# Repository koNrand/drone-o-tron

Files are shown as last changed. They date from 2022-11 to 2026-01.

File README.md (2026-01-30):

# *Drone o Tron* ->[Veröffentlichung/Publication](https://www.instagram.com/p/Cwxmp4OM5u2/?img_index=1)<-

Für Neulinge: Lade dieses Repository herunter, um die Dateien zu benutzen. Ein Öffnen über den Browser funktioniert in der Regel nicht! Klicke dazu auf den grünen Button 'Code' und dann auf 'Download ZIP'.

For newbies: Download this repository to use the files. Opening them via the browser usually does not work! Click on the green button 'Code' and then on 'Download ZIP'.

----------

english below

## DE:

Der ***Drone o Tron*** (DoT) ist einstimmiger Minisynthesizer mit Ribbonklaviatur, welche über ein Monoaudiokabel gesteuert wird. Inspiration hierfür sind der [Monotron]((https://www.korg.com/de/products/dj/monotron/index.php)) von Korg oder die [Pocket Operator](https://teenage.engineering/products/po) von Teenage Engineering. Der Synthesizer soll auf eine einzige, handliche Platine passen und mit zwei AAA-Batterien betrieben werden. Außerdem soll es einige einstellbare Effekte und Filter geben, über welche der Sound verändert werden kann.

In den Pre-Versionen bestehen aus der Simulation in [LTSpice](https://www.analog.com/en/design-center/design-tools-and-calculators/ltspice-simulator.html) und dem Testaufbau auf dem Steckbrett. Wer Interesse am kompletten Prozess des Projektes hat, oder Erklärungen zu den Teilschaltungen sucht, kann im `.archive`-Ordner vorbeischauen. Ich habe dort in den `README.md` die entsprechenden Infos und auch Erklärvideos zu den groben Grundlagen verlinkt. 

Als finalen Schritt im Projektmanagement und erste Hauptversion nach Simulation und Steckbrettaufbau habe ich nun  den Drone o Tron in [KiCad](kicad.org/) Schaltplaneditor und anschließend im Boardeditor aufgebaut. Ich habe auch hier nochmal einige Änderungen vorgenommen, neue Funktionen hinzugefügt und diese in einem selbst illustrierten Platinenlayout zusammenkommen lassen.

Eine Auflistung aller Änderungen findet sich in der `CHANGELOG.md`.

Die voll funktionsfähige Platine lässt sich für den eigenen Gebrauch mithilfe der `gerberfiles_v_1_0_rev1`-Ordner bestellen. EInfach die geünschte Version und dann bei PCB-Produzenten wie JLCPCB bestellen. Eine interaktive Aufbauhilfe (`interactive_assembly_list.html`) in Form einer .html Datei ist auch vorhanden, sodass die benötigen Bauteile auch keine Hürde darstellen.
Mögliche Händler hier sind LCSC, (zugehörig zu JLCPCB, einfachste Lösung) Mouser, Reichelt, TME, uvm.

### Außer dem KiCadprojekt sind enthalten:
- einige gerenderte Aufnahmen aus der 3D-Ansicht von KiCad, welche alle 3D-Bauteilmodelle, die Illustrationen und meien favorisierte Farbe für den Lötstoplack (lila) enthalten.
- S/W Vektorgrafikaufnahmen des Boards, welceh mithilfe des Board2Pdf-Plugins erstellt wurden
- eine BOM-Tabelle (Bill of Material) aller benötigter Bauteile
- eine aussführliche Bescheibung der Berechnungen, die ich für den Spannungsteiler der Klaviatur vorgenommen habe, sodass der NE555 als wohltemperierter VCO für tonale Musik verwendet werden kann

## Disclaimer
Mit jegllicher Änderung am Schaltplan oder dem Boarddesign erlischt 
die Nutzungserlaubnis der Board-Artworks, meines Logos sowie der Verwendung meiner
Referenzen. Eine Nennung des Originalurhebers ist jedoch unbedingt erwünscht
und entsprechend zu kennzeichnen. Eine Veröffentlichung der veränderten Schaltung muss unter derselben Creative Commons Lizens CC BY-NC-SA erfolgen. Die 
kommerzielle Nutzung ist ausgeschlossen. Alles frei nach dem Motto: Fair use only! ;-)

Mehr Informationen unter: https://creativecommons.org

Open hardware FTW <3

-------

## EN:
The ***Drone o Tron*** (DoT) is monophonic mini synthesizer with ribbon keyboard, which is controlled by a mono audio cable. Inspiration for this is the [Monotron]((https://www.korg.com/de/products/dj/monotron/index.php)) by Korg or the [Pocket Operator](https://teenage.engineering/products/po) by Teenage Engineering. The synthesizer is supposed to fit on a single, handy circuit board and run on two AAA batteries. There are also supposed to be some adjustable effects and filters through which the sound can be changed.

In the pre-versions consist of the simulation in [LTSpice](https://www.analog.com/en/design-center/design-tools-and-calculators/ltspice-simulator.html) and the test setup on the breadboard. If you are interested in the complete process of the project, or if you are looking for explanations of the subcircuits, you can have a look in the `.archive` folder. I have linked there in the `README.md` the corresponding info and also explanatory videos to the rough basics. 

As a final step in the project management and first main version after simulation and board assembly I have now built the Drone o Tron in [KiCad](kicad.org/) schematic editor and afterwards in the board editor. Again, I made some changes, added new features and let them come together in a self-illustrated board layout.

A list of all changes can be found in the `CHANGELOG.md`.

The fully functional board can be found for your own use with the help of the `.gerberfiles_v_1_0_rev0` folder. Choose your favorite version and zip it. The board can then be ordered from PCB producers like JLCPCB. An interactive assembly help (`interactive_assembly_list.html`) in form of a .html file is also available, so that the needed components are no hurdle. Possible distributors here are LCSC, (belonging to JLCPCB, simpliest solution) Mouser, Reichelt, TME, and many more.

### Besides the KiCad project, included are:
- some rendered shots from the 3D view of KiCad, containing all 3D component models, the illustrations and my favorite color for the solder mask (purple).
- B/W vector graphic images of the board, which were created using the Board2Pdf plugin
- a BOM table (Bill of Material) of all needed components
- a detailed description of the calculations I did for the keyboard voltage divider, so that the NE555 can be used as a well-tempered VCO for tonal music

## Disclaimer
With any change to the schematic or the board design the usage permission of the 
the permission to use the board artwork, my logo and the use of my references.
references. A naming of the original author is however absolutely desired
and must be marked accordingly. A publication of the modified circuit must be made under the same Creative Commons license CC BY-NC-SA. The 
commercial use is excluded. Everything freely after the slogan: Fair use only! ;-)

More information at: https://creativecommons.org

Open hardware FTW <33

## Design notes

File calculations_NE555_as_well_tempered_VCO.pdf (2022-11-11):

wohltemperierte Halbtöne für den Drone-o-Tron (DOT) / well-tempered semitones for the Drone-o-Tron (DOT)

U_CV [V] | f_soll [Hz] | Ton | Kammerton A | 440Hz
2.914 | 23.12465143 | F# | nicht linear/non linear (OPV clippt, opam is clipping) | A | 220Hz
2.878 | 24.49971476 | G | nicht linear | | A | 110Hz
2.858 | 25.95654361 | G# | | | A | 55Hz
2.848 | 27.50000001 | A | Faktor: | 1.05946309 | A | 27.5Hz
2.834 | 29.1352351 | A# | | | G# | 25.9565436
2.817 | 30.86770634 | B | | | G | 24.4997148
2.798 | 32.70319567 | C
2.775 | 34.64782888 | C#
2.749 | 36.708096 | D
2.719 | 38.89087298 | D#
2.686 | 41.20344463 | E
2.647 | 43.65352894 | F
2.603 | 46.24930285 | F#
2.551 | 48.99942951 | G
2.494 | 51.91308721 | G#
2.423 | 55.00000002 | A
2.347 | 58.27047021 | A#
2.257 | 61.73541268 | B
2.155 | 65.40639135 | C
2.032 | 69.29565777 | C#
1.889 | 73.416192 | D
1.7066 | 77.78174596 | D#
1.4499 | 82.40688926 | E
| 87.30705789 | F
| 92.49860571 | F#

DE: Der Drone-o-Tron (DOT) verfügt über zwei Spielarten. Zum einen ist der Pitch im "Dronemode" (Drone I) stufenlos über ein Potentiometer einstellbar. So kann jede Frequenz des Drone-o-Tron getroffen werden. Im tonalen Modus (Drone O) soll der Drone-o-tronüber eine Metallklaviatur auf der Platine direkt spielbar sein. Dies funktioniert über die VCO-Funktionalität des NE555. (VCO = Voltage Controllable Oscillator, also Frequenz/Tonhöhe steuerbar durch Spannung) Diese Steuerung soll ganze klassisch über das heute allgemein gültige wohltemperierte System laufen, sodass der Frequenzunterschied zwischen zwei Tasten einem Halbtonschritt entspricht. Dazu wurde für einen statischen Bereich des DOT die niedrigste mögliche Frequenz am Ausgang gemessen.
f_min (minimale Frequenz) wird erreicht beiU_CV = Versorgungsspannung = 3V. Da der Eingangsbuffer-OPV jedoch bei Spannungen so nah an der Spannungsversorgung nicht mehr linear verstärkt, wurde als höchste Spanung 2.858V (später erkennbar, warum) gewählt. Diese erzeugt am Ausgang eine Frequenz von 25.96Hz, was einem G# relativ zum Kammerton A=440Hz entspricht.
Ziel ist es jetzt zum einen den Tonumfang des DOT in einem statischen Bereich (nur durch Aussteueerung des NE555 als VCO) zu vermessen und einen Spannungsteiler für die Klaviatur zu berechnen, sodass die auf den Tasten erzeugten Spannungen, welche über ein Audiokabel beim Spielen an den NE555-VCO-Eingang gehen, auch wirklich Noten aus dem wohltemperierten System mit seinen Halbtonschritten erzeugen.
Dazu wurden nun dieFrequenzen für den Tonumfang von knapp zwei Oktaven über G# (25.96Hz) berechnet. Anschließend wurden die am VCO-Eingang des NE555 benötigten Spannungen gemessen, um diese berechneten Frequenzen zu erhalten. Das Ergebnis ist in der folgenden Tabelle erkennbar.

EN: The Drone-o-Tron (DOT) has two modes of play. On one hand, the pitch in "Dronemode" (Drone I) is continuously adjustable via a potentiometer. So every frequency of the Drone-o-Tron can be hit. In tonal mode (Drone O), the Drone-o-tron is supposed to be directly playable via a metal keyboard on the circuit board. This works via the VCO functionality of the NE555. (VCO = Voltage Controllable Oscillator, i.e. frequency/pitch controllable by voltage) This control is supposed to run in a whole classical way via the today generally valid well-tempered system, so that the frequency difference between two keys corresponds to a semitone step. For this purpose, the lowest possible frequency at the output was measured for a static range of the DOT.
f_min (minimum frequency) is reached at U_CV = supply voltage = 3V. However, since the input buffer OPV no longer amplifies linearly at voltages this close to the power supply, 2.858V was chosen as the highest voltage (we will see why later). This produces a frequency of 25.96Hz at the output, which corresponds to a G# relative to the concert pitch A=440Hz. The goal now is to measure the rangeofthe DOT in a static range (only by using the NE555 as VCO) and to calculate a voltage divider for the keyboard, so that the voltages generated on the keys, which goes to the NE555 VCO input via an audio cable when playing, really generates notes from the well-tempered system with its semitone steps.
For this purpose, the frequencies for the range of just under two octaves above G# (25.96Hz) were calculated. Then the voltages required at the VCO input of the NE555 were measured to obtain these calculated frequencies. The result can be seen in the following table.

DE: Heute ist das zwölfstufig gleichschwebende („wohltemperierte“) System allgemein üblich, bei der alle Halbtonschritte eine feste Proportion von 1:1,059463094359 haben.

EN: Today, the twelve-step equal temperament ("well-tempered") system is generally used, in which all semitone steps have a fixed proportion of 1:1.059463094359.

https://www.lernhelfer.de/schuelerlexikon/musik/artikel/intervalle

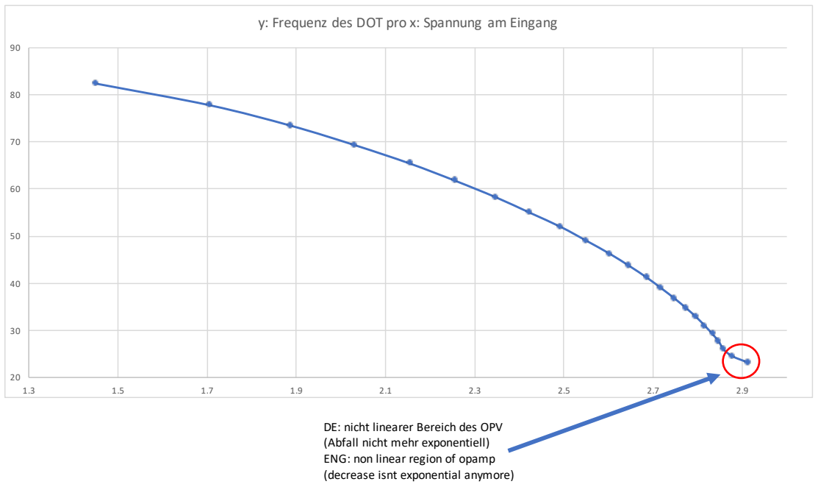
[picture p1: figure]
DE: nicht linearer Bereich des OPV (Abfall nicht mehr exponentiell) ENG: non linear region of opamp (decrease isnt exponential anymore)

y: Frequenz des DOT pro x: Spannung am Eingang

DE: Aus den Messwerten sind nun drei Informationen abzuleiten. Zum einen hat der NE555 ein exponentielles Verhalten zwischen Eingangsspannung und Ausgangsfrequenz. Demenstsprechend wird ein exponentieller Spannungsteiler benötigt, d.h. die Widerstände besitzen alle einen unterschiedlichen Wert. Davon ausgehend ist nun die zweite wichtige Sache zu erkennen. Bei den Spannungen über 2.9V mischt sich in die NE555-Kurve die nichtlinearität der verwendeten OPVs ein. Diese kommen zwar bis nahezu an ihre Versorgungsrail, (3V) jedoch ist das Verhalten nicht mehr linear und daher nicht für die Berechnung des Spannungsteilers zu gebrauchen. Daher werden diese beiden Werte verworfen. Die dritte erkennbare Inforamtion ist, dass der NE555 im statischen VCO-Modus keine zwei Oktaven Frequenzbereich hat. Die niedrigste Frequenz wird bei U_ein = 3V, die höchste bei Uein = 1.1V erreicht. Das hat etwas mit dem inneren Aufbau des Präzisionsschmitttrigger-ICs zu tun und kann extern nicht geändert werden. Bei U_ein = 1.1V kommt der NE555 jedoch nicht mehr an die Note F (siehe Tabelle oben) heran, sodass für die zweite volle Okatve leider drei Halbtöne fehlen. Das ist aber kein Problem für die Spielweise, so wird der DOT nur eine einzige Oktave auf der Klaviatur haben.

EN: Three pieces of information can now be derived from the measured values. First, the NE555 has an exponential behavior between input voltage and output frequency.Accordingly, an exponential voltage divider is required, i.e. the resistors all have a different value. Starting from this
now the second important thing to recognize: At voltages above 2.9V the nonlinearity of the used OPamps mixes into the NE555 curve. These
reach almost their supply rail (3V), but the behavior is no longer linear and therefore not to be used for the calculation ofthe voltage divider.
Therefore these two values are discarded. The third recognizable information is that the NE555 in static VCO mode does not have two octaves of frequency range. The lowest frequency is set at U_in = 3V, the highest at U_in = 1.1V. This has something to do with the internal design of the precision Schmitt trigger IC and cannot be changed externally.At U_in = 1.1V, however, the NE555 no longer approaches the note F (see table above), so unfortunately three semitones are missing for the second full octave. But this is not a problem for playing, so the DOT will have only one octave on the keyboard.

DE: Mit den nun gesammelten Informationen und Messwerten soll nun ein Spannungsteiler berechnetwerden, welcher zwölf Kontrollspannungen ausgibt, (12 Noten = 1 Oktave) für die zwölf Noten einer Oktave. Dazu wird von den obigen Messwerten ein Oktavsprung von A zu genommen, da dieser eine runde Anfangs- und Endfrequenz hat und im linearen Bereich des OPV liegt. Als Gesamtwiderstand des Spannungsteilers werden 10kΩ festgelegt.

EN: With the now collected information and measured values a voltage divider is to be calculated, which outputs are twelve control voltages, (12 notes = 1 octave) for the twelve notes of an octave. For this purpose, an octave step of A is taken from the above measured values, since this has a round start and end frequency and lies in the linear range of the Opamp. The total resistance of the voltage divider is set to 10kΩ.

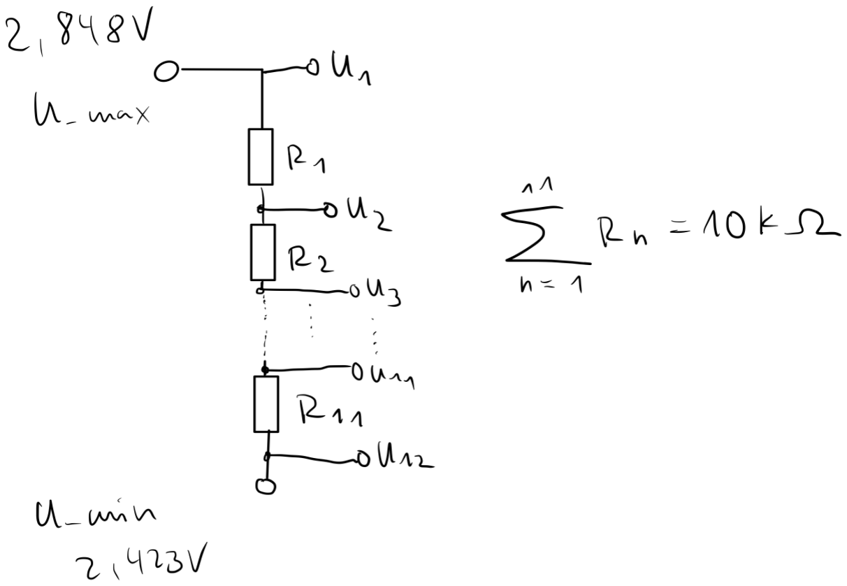
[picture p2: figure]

DE: Zur leichteren Berechnung und da auf der Platine U_min und U_max frei einstellbar sind, ziehen wir den Offset von 2.423 V von U_min und U_max ab.

EN: For easier calculation and because U_min and U_max are freely adjustable on the board, we subtract the offset of 2.423 V from U_min and U_max.

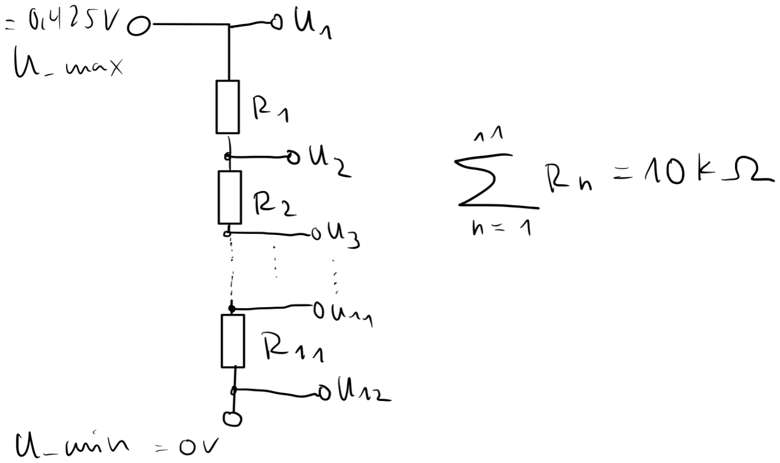
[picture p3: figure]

DE: Nun beginnen wir von oben nach unten für alle Ausgangsspannungen U_1 bis U_12 den Ausgangswiderstand zu berechnen. Aus der Differenz zum konstanten Eingangswiderstand von 10kΩ erhalten wird die Ausgangswiderstände. Durch eine anschließende Iteration der Messwert von unten nach oben und die Subtraktion vom vorherigen Ausgangswiderstand erhalten so die Widerstände R_1 bis R_11. Die entsprechende Berechnung ist in der folgenden Tabelle erkennbar.

EN: Now we start to calculate the output resistance from top to bottom for all output voltages U_1 to U_12. From the difference to the constant input resistance of 10kΩ we get the output resistances. By a subsequent iteration of the measured value from bottom to top and the subtraction from the previous output resistance we get the resistances R_1 to R_11. The corresponding calculation can be seen in the following table.

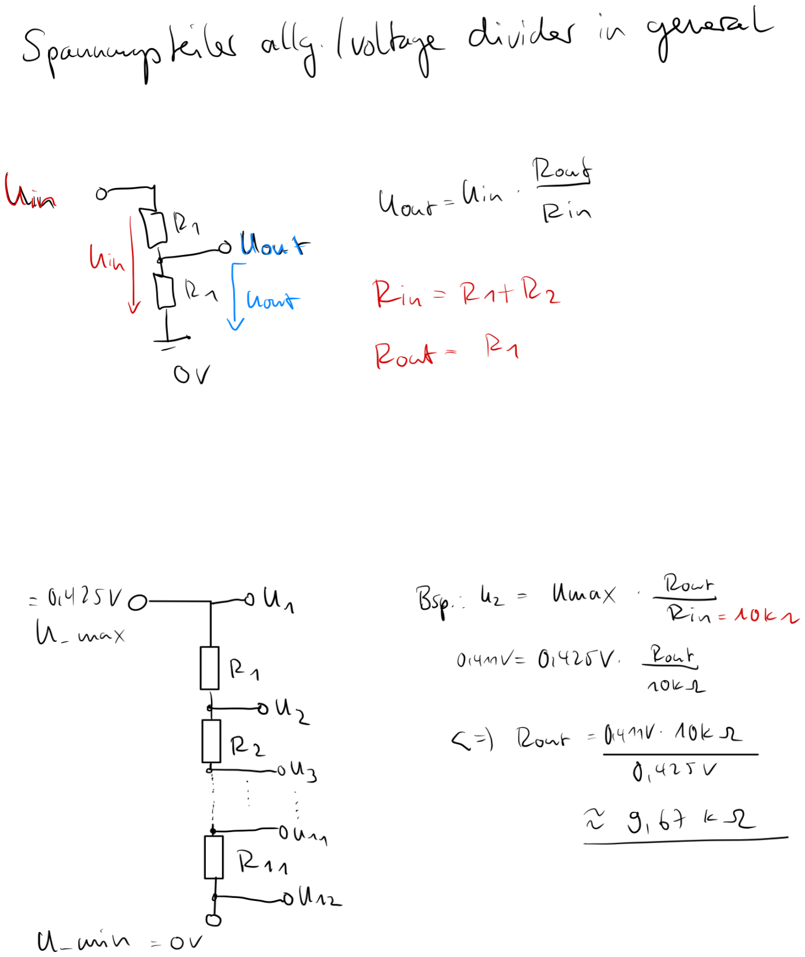
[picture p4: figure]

U_min - offset (im | f. Halbtonschritte: | U_aus rel. | Span.Bereich | theor. | theor. | Diff. zum Vor- | Diff. zum Vor- | nächster widerstand aus
Spannungsteiler) | U_gesucht | zu offset | U_ein | R_ein [kΩ] | R_aus | widerst.[kΩ] | widerst.[Ω] ger. E96 Reihe
2.423 | 2.848 | 0.425 | 0.425 | 10 | 10 | 0.329411765 | 329 | 330
2.423 | 2.834 | 0.411 | 0.425 | 10 | 9.670588235 | 0.4 | 400 | 402
2.423 | 2.817 | 0.394 | 0.425 | 10 | 9.270588235 | 0.447058824 | 447 | 442
2.423 | 2.798 | 0.375 | 0.425 | 10 | 8.823529412 | 0.541176471 | 541 | 536
2.423 | 2.775 | 0.352 | 0.425 | 10 | 8.282352941 | 0.611764706 | 612 | 619
2.423 | 2.749 | 0.326 | 0.425 | 10 | 7.670588235 | 0.705882353 | 706 | 698
2.423 | 2.719 | 0.296 | 0.425 | 10 | 6.964705882 | 0.776470588 | 776 | 787
2.423 | 2.686 | 0.263 | 0.425 | 10 | 6.188235294 | 0.917647059 | 918 | 910
2.423 | 2.647 | 0.224 | 0.425 | 10 | 5.270588235 | 1.035294118 | 1035 | 1050
2.423 | 2.603 | 0.18 | 0.425 | 10 | 4.235294118 | 1.223529412 | 1224 | 1210
2.423 | 2.551 | 0.128 | 0.425 | 10 | 3.011764706 | 1.341176471 | 1341 | 1330
2.423 | 2.494 | 0.071 | 0.425 | 10 | 1.670588235 | 1.670588235 | 1671 | 1690
2.423 | 2.423 | 0 | 0.425 | 10 | 0
| | | | | Summen: | 10 | 10000 | 10004
U_min - offset (im | f. Halbtonschritte: | U_aus rel. | Span.Bereich | tats. | tats. | nächster widerstand aus | | Spannung
2.423 2.423 2.423 2.423 2.423 2.423 2.423 2.423 2.423 2.423 2.423 2.423 2.423 | 2.848 2.834 2.817 2.798 2.775 2.749 2.719 2.686 2.647 2.603 2.551 2.494 2.423 | 0.425 0.411 0.394 0.375 0.352 0.326 0.296 0.263 0.224 0.18 0.128 0.071 0 | 0.425 0.425 0.425 0.425 0.425 0.425 0.425 0.425 0.425 0.425 0.425 0.425 0.425 | 10004 10004 10004 10004 10004 10004 10004 10004 10004 10004 10004 10004 10004 | 10004 9674 9272 8830 8294 7675 6977 6190 5280 4230 3020 1690 0 | 330 402 442 536 619 698 787 910 1050 1210 1330 1690 0 | 2.848 2.833980608 2.816902439 2.79812495 2.775354058 2.749057077 2.719403938 2.685969812 2.647310276 2.602703119 2.551298681 2.494796281 2.423 | 0 0.00068427 0.00346329 0.00446569 0.01275886 0.00207629 0.01485614 0.0011239 0.01172179 0.01140535 0.01170837 0.03192789 0
Spannungsteiler) | U_gesucht | zu offset | U_ein | R_ein [Ω] | R_aus [Ω] | E96 Reihe | U_aus | Fehler[%]

max_Fehler [%] =0.031927886 øFehler [%] = 0.009653804

DE: Diese nun berechneten Widerstände wurden anschließend in der vorletzten Spalte auf ganzzahlige Werte für gerundet. Schließlich wurden aus der E96-Reihe die am nächsten liegenden, realen Widerstandsgrößen rausgesucht und notiert. Diese sollen nun für den Spannungsteiler auf dem Board verwendet werden.
Im Gesamtwiderstand des E96-Spannungsteilers ergibt sich dabei eine Abweichung von nur 4Ω, was 0.04% entspricht.
Als letzter Kontrollschritt wurden für diesen E96-Spannungsteiler rückwärts die Spannungen an den Ausgangsknoten berechnet, um diese mit den ganz am Anfang gemessenen und gesuchten EIngangsspannungen zu vergleichen und den prozentualen Fehler zu berechnen.

EN: These now calculated resistances were then rounded to integer values in the second last column. Finally, the closest real resistance values were selected from the E96 series and noted down. These are now to be used for the voltage divider on the board.
In the total resistance of the E96 voltage divider, this results in a deviation of only 4Ω, which corresponds to 0.04%.
As a last control step, the voltages at the output nodes were calculated backwards for this E96 voltage divider in order to compare them with the input voltages measured and searched for at the very beginning and to calculate the percentage error.

DE: Aus der Kontrollrechnung geht eine maximale Abweichung der Ausgangsspannung von von 0.032% bei durchschnittlich 0.0097%. Bei den schließlich verwendeten Widerstand im DOT handelt es sich um Metalloxidwiderstände mit einer Toleranz von maximal einem Prozent, sodass davon ausgegangen werden kann, dass das kaum bis nicht hörbare Abweichungen erzeugt.

EN: From the control calculation, a maximum deviation of the output voltage of 0.032% with an average of 0.0097%. The resistors finally used in the DOT are metal oxide resistors with a maximum tolerance of one percent, so it can be assumed that this produces hardly audible to non-audible deviations.

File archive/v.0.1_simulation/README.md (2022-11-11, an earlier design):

# *Drone o Tron* v.0.1

Der ***Drone o Tron*** (DoT) ist einstimmiger Minisynthesizer mit Ribbonklaviatur, welche über ein Monoaudiokabel gesteuert wird. Inspiration hierfür sind der [Monotron]((https://www.korg.com/de/products/dj/monotron/index.php)) von Korg oder die [Pocket Operator](https://teenage.engineering/products/po) von Teenage Engineering. Der Synthesizer soll auf eine einzige, handliche Platine passen und mit zwei AAA-Batterien betrieben werden. Außerdem soll es einige einstellbare Effekte geben, über welche der Sound verändert werden kann.

Schritte im Projektmanagement:
- [x] Ideen sammeln
- [ ] konkrete Schaltungen finden 
- [ ] Teilschaltungen in LTSpice simulieren, um erste Konfiguration zu erhalten.

### konkrete Schaltungen finden
Als Herz des DoT soll der NE555 (Präzisionsschmitttrigger IC) fungieren, welcher in einer astabilen Kippstufenkonfiguration als VCO (voltage controlled oscillator = Spannung abh. von Eingangsspannung) über den *CV/CTRL*-Eingang betrieben wird. Die Kontrollspannung (=engl. *control voltage*, kurz *CV*) soll von einer Klaviatur kommen, welche über einen Spannungsteiler für jeden Ton eine andere Spannung erzeugt. Anschließend sollen Rechteck- (Ausgang) und Dreieckspannung (am Kondensator) abgegriffen und über ein Potentiometer gemischt werden. Schließlich soll das Signal durch einen zweipoligen Tiefpassfilter laufen, bei welchem über zwei Potentiometer Grenzfrequenz und die Stärke der Resonanz am Knickpunkt des Filters eingestellt werden können.

### Teilschaltungen in LTSpice simulieren, um erste Konfiguration zu erhalten.

Im Folgenden habe ich die Schaltungsideen in [LTSpice](https://www.analog.com/en/design-center/design-tools-and-calculators/ltspice-simulator.html) in der `Simulation.asc`-Datei aufgebaut und werde hier noch ein bisschen den Aufbau erläutern.
(*Hinweis*: LTSpice ist ein Schaltungssimulationsprogramm von Analog.com, Tutorials dazu finden sich bspw. auf YouTube.)

Der NPN-BJT Q1 hat die Aufgabe, den NE555 ein- und auszuschalten.
(als krude Hüllkurve - der Ton kommt nur, wenn eine Taste gedrückt wird)
Durch die Idealität des NE555-Models kann bei der Verschaltung von Q1 
LTSpice keine Startbedingung finden, weshalb der IC direkt an GND 
hängt und nicht an Q1.
Es gibt:

- zwei Trimpotentiometer, um Feinjustierungen der Maximal- und Minimaltonhöhe vorzunehmen. (in der Simulation zwei feste Widerstandspaare)
- Potentiometer, um Tastgrad des Signals zu verändern (0-50 %)
- Potentiometer für Fade zwischen Dreieck- und Rechtecksignal
- Potentiometer für Knickfrequenz eines 2-Pol-Tiefpassfilters
- Potentiometer, um Resonanz des Filters zu ändern
- mithilfe der .param-Befehle lassen sich die Stellungen der verschiedenen Poteiometer von 0 (links) bis 1 (rechts) einstellen
- mithilfe von .step param lassen sich mehrere Simualtionen mit unterschiedlichen Parametern für die Potentiometer simulieren
- mit dem .wave Befehl wird eine .wav-Datei des Ausgangssignals erzeugt, um sich das Ergebnis anhören zu können

Die Wahl einiger Zeitkonstanten scheint vielleicht nicht sinnvoll, zielt
 aber auf eine Effizienz bei der Simulationszeit ab. 
 *Nachtrag:* Das kann auch durch einen späteren Start der Datenaufnahme in der Transientenanalyse geschehen.

Damit ist die Simulation beendet und als nächster Schritt werde ich die Schaltung auf de Steckbrett aufbauen und weiter testen und gegebenfalls erweitern.

### Achtung
Mit jegllicher Änderung am Schaltplan erlischt 
die Nutzungserlaubnis meines Namens sowie der Verwendung meiner Referenzen. Eine Nennung des Originalurhebers ist jedoch unbedingt erwünscht und entsprechend zu kennzeichnen. Eine Veröffentlichung der veränderten Schaltung muss unter derselben Creative Commons Lizens CC BY-NC-SA erfolgen. Die 
kommerzielle Nutzung ist ausgeschlossen. Alles frei nach dem Motto: Fair use only! ;-)

Open hardware FTW <3

---

## EN:
The ***Drone o Tron*** (DoT) is monophonic mini synthesizer with ribbon keyboard, which is controlled by a mono audio cable. Inspiration for this is the [Monotron]((https://www.korg.com/de/products/dj/monotron/index.php)) by Korg or the [Pocket Operator](https://teenage.engineering/products/po) by Teenage Engineering. The synthesizer is supposed to fit on a single, handy circuit board and run on two AAA batteries. There shall also be some adjustable effects through which the sound can be changed.

Steps in project management:
- [x] collect ideas
- [ ] find concrete circuits 
- [ ] simulate partial circuits in LTSpice to get first configuration.

## find concrete circuits 
The heart of the DoT will be the NE555 (precision Schmitt trigger IC), which will be operated in an astable toggle configuration as a VCO (voltage controlled oscillator) via the *CV/CTRL* input. The control voltage (*CV*) shall come from a keyboard, which generates a different voltage for each tone via a voltage divider. Subsequently, square wave (output) and triangle voltage (at the capacitor) are to be tapped and mixed via a potentiometer. Finally, the signal is to pass through a two-pole low-pass filter, where two potentiometers can be used to set the cutoff frequency and the amount of resonance at the filter's inflection point.

### simulate partial circuits in LTSpice to get first configuration

In the following I have built the circuit ideas in [LTSpice](https://www.analog.com/en/design-center/design-tools-and-calculators/ltspice-simulator.html) in the `Simulation.asc` file and will explain a bit more about the setup here.
(*Note*: LTSpice is a circuit simulation program from Analog.com, tutorials can be found on YouTube for example).

The NPN-BJT Q1 has the task to switch the NE555 on and off.
(as a crude envelope - the sound only comes when a key is pressed).
Due to the idealistic nature of the NE555 model, when connecting Q1 
LTSpice can't find a start condition,so the IC is connected directly to GND 
and not to Q1.
There are:

- two trimpoteniometers to make fine adjustments of maximum and minimum pitch. (in the simulation two fixed resistor pairs)
- potentiometer to change duty cycle of the signal (0-50%)
- potentiometer for fade between triangle and square wave signal
- potentiometer for kink frequency of a 2-pole low pass filter
- potentiometer to change resonance of the filter
- using .param commands you can set the positions of different poteiometers from 0(left) to 1 (right)
- use .step param to simulate several simualtions with different parameters for the potentiometers
- with the .wave command a .wav file of the output signal is created to be able to listen to it

The choice of some time constants may not seem reasonable, but it aims at
 but aims at efficiency in simulation time. 
 *Supplement:* This can also be done by starting the data recording later in the transient analysis.

This is the end of the simulation and as a next step I will build the circuit on a breadboard and test it further and extend it if necessary.

### Attention
With any change to the schematic the permission to use 
the permission to use my name and my references.
references. A naming of the original author is however absolutely desired
and must be marked accordingly. A publication of the modified circuit must be made under the same Creative Commons license CC BY-NC-SA. A 
commercial use is excluded. All according to the motto: Fair use only ;-)

More info at: https://creativecommons.org

Open hardware FTW <3

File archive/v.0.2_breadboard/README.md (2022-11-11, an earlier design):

# *Drone o Tron* v.0.2

## DE:
Der ***Drone o Tron*** (DoT) ist einstimmiger Minisynthesizer mit Ribbonklaviatur, welche über ein Monoaudiokabel gesteuert wird. Inspiration hierfür sind der [Monotron]((https://www.korg.com/de/products/dj/monotron/index.php)) von Korg oder die [Pocket Operator](https://teenage.engineering/products/po) von Teenage Engineering. Der Synthesizer soll auf eine einzige, handliche Platine passen und mit zwei AAA-Batterien betrieben werden. Außerdem soll es einige einstellbare Effekte und Filter geben, über welche der Sound verändert werden kann.

Im ersten Schritt habe ich mich für einen ersten groben Aufbau der Gesamt- und Teilschaltungen, bestehend aus Klaviatur, VCO, Timbrepotentiometer und Filter, entschieden und diese mithilfe von [LTSpice](https://www.analog.com/en/design-center/design-tools-and-calculators/ltspice-simulator.html) simuliert, um zum einen die Idee zu verifzieren und einen groben Aufbau zu erhalten. Die entsprechen Infos befinden sich im `.archive`-Ordner. Wer etwas Hilfe beim Verständnis für die Schaltungen benötigt, den kann ich unter anderem auf mein [praxisorierntiertes OPV-Grundlagentutorial](https://www.youtube.com/playlist?list=PLFoTc99xXplpeMX_rCe2f8oruM441F54b) auf YouTube verweisen. Nun gehts es weiter im Projektmangement:

Schritte im Projektmanagement:
- [x] Ideen sammeln, Recherche, Simulation
- [ ] Steckbrettaufbau
 
### Steckbrettaufbau
  
Grob gesagt habe ich die Schaltung einfach mal auf dem Steckbrett aufgebaut, Bauteile geändert, weitere Teilschaltungen hinzugefügt und allgemein so lange rumprobiert, bis mir die Sounds gefallen haben. Die konkreten Änderungen befinden sich in der `CHANGELOG.md`. Außerdem habe ich einige Hörbeispiele aufgenommen und mit dem Oszilloskop visualisiert, welche sich auf YouTube in meiner [*Drone o Tron*-Playlist](https://youtube.com/playlist?list=PLFoTc99xXplrwt37A0d1chDFaE8vJPAfo) befinden. Ein Bild des Steckbrettaufbaus findet sich in `beadboard_steckbrett.HEIC`. Den bisherigen Schaltplan (`schematic_schaltplan.kicad_sch`) habe ich dann noch zur besseren Übersicht mit der Schaltplan- und Boarderstellungssoftware [KiCad](kicad.org/) erstellt. Eine Playlist mit einem einfachen Grundlagentutorial findet sich -> [hier](https://www.youtube.com/playlist?list=PLFoTc99xXplq-vwjNqq9S3VKb1se5qiRt) <-

### Disclaimer
Mit jegllicher Änderung am Schaltplan erlischt 
die Nutzungserlaubnis meines Namens sowie der Verwendung meiner
Referenzen. Eine Nennung des Originalurhebers ist jedoch unbedingt erwünscht
und entsprechend zu kennzeichnen. Eine Veröffentlichung der veränderten Schaltung muss unter derselben Creative Commons Lizens CC BY-NC-SA erfolgen. Die 
kommerzielle Nutzung ist ausgeschlossen. Alles frei nach dem Motto: Fair use only! ;-)

Mehr Informationen unter: https://creativecommons.org

Open hardware FTW <3

-------

## Drone o Tron

## EN:
The ***Drone o Tron*** (DoT) is monophonic mini synthesizer with ribbon keyboard, which is controlled by a mono audio cable. Inspiration for this is the [Monotron]((https://www.korg.com/de/products/dj/monotron/index.php)) by Korg or the [Pocket Operator](https://teenage.engineering/products/po) by Teenage Engineering. The synthesizer is supposed to fit on a single, handy circuit board and run on two AAA batteries. There should also be some adjustable effects and filters through which the sound can be changed.

In the first step I decided on a first rough construction of the total and partial circuits, consisting of keyboard, VCO, timbre potentiometer and filter, and simulated these with the help of [LTSpice](https://www.analog.com/en/design-center/design-tools-and-calculators/ltspice-simulator.html), in order to verify the idea on the one hand and to get a rough construction on the other hand. The corresponding info can be found in the `.archive` folder. If you need some help to understand the circuits, I can refer you to my [praxisorierntiertes OPV-Grundlagentutorial](https://www.youtube.com/playlist?list=PLFoTc99xXplpeMX_rCe2f8oruM441F54b) on YouTube. Now it goes on in the project management:

Steps in Project Management:
- [x] Collect ideas, research, simulation
- [ ] breadboard construction
 
### breadboard construction
  
Roughly speaking, I simply built up the circuit on the breadboard, changed components, added more subcircuits and generally tried things out until I liked the sounds. The concrete changes can be found in the `CHANGELOG.md`. I also recorded some audio samples and visualized them with the oscilloscope, which are on YouTube in my [*Drone o Tron* playlist](https://youtube.com/playlist?list=PLFoTc99xXplrwt37A0d1chDFaE8vJPAfo). A picture of the breadboard can also be found under `beadboard_steckbrett.HEIC`. I then created the previous schematic (`schematic_schaltplan.kicad_sch`) with the schematic and board creation software [KiCad](kicad.org/) for a better overview. A playlist with a simple basic tutorial can be found -> [here](https://www.youtube.com/playlist?list=PLFoTc99xXplq-vwjNqq9S3VKb1se5qiRt) <-

### Disclaimer
With any change of the schematic the permission to use 
the permission to use my name and my references.
references. A naming of the original author is however absolutely desired
and must be marked accordingly. A publication of the modified circuit must be made under the same Creative Commons license CC BY-NC-SA. The 
commercial use is excluded. Everything freely after the slogan: Fair use only! ;-)

More information at: https://creativecommons.org

Open hardware FTW <3

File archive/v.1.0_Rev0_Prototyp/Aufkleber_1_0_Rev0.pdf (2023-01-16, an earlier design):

x 2
AAA Batterie

x 2
AAA Batterie

x 2
AAA Batterie

x 2
AAA Batterie

x 2
AAA Batterie

x 2
AAA Batterie

x 2
AAA Batterie

x 2
AAA Batterie

x 2
AAA Batterie

x 2
AAA Batterie

x 2
AAA Batterie

x 2
AAA Batterie

x 2
AAA Batterie

x 2
AAA Batterie

Platine ist RoHS
konform

Platine ist RoHS
konform

Platine ist RoHS
konform

Platine ist RoHS
konform

Platine ist RoHS
konform

Platine ist RoHS
konform

Platine ist RoHS
konform

Platine ist RoHS
konform

Platine ist RoHS
konform

Platine ist RoHS
konform

Platine ist RoHS
konform

Platine ist RoHS
konform

Platine ist RoHS
konform

Platine ist RoHS
konform

Platine ist RoHS
konform

Platine ist RoHS
konform

Platine ist RoHS
konform

Platine ist RoHS
konform

Platine ist RoHS
konform

Platine ist RoHS
konform

Platine ist RoHS
konform

M3 Schraube
+ Mutter

x 2

f. Batteriefach

M3 Schraube
+ Mutter

x 2

f. Batteriefach

M3 Schraube
+ Mutter

x 2

f. Batteriefach

M3 Schraube
+ Mutter

x 2

f. Batteriefach

M3 Schraube
+ Mutter

x 2

f. Batteriefach

M3 Schraube
+ Mutter

x 2

f. Batteriefach

M3 Schraube
+ Mutter

x 2

f. Batteriefach
1_0_Rev0 | 1_0_Rev0 | 1_0_Rev0 | 1_0_Rev0 | 1_0_Rev0 | 1_0_Rev0 | 1_0_Rev0

M3 Schraube
+ Mutter

x 2

f. Batteriefach
| M3 Schraube + Mutter
x 2
f. Batteriefach
| | M3 Schraube + Mutter
x 2
f. Batteriefach
| | | M3 Schraube + Mutter
x 2
f. Batteriefach
| | | | M3 Schraube + Mutter
x 2
f. Batteriefach
| | | | | M3 Schraube + Mutter
x 2
f. Batteriefach
| | | | | | M3 Schraube + Mutter
x 2
f. Batteriefach
1_0_Rev0 | 1_0_Rev0 | 1_0_Rev0 | 1_0_Rev0 | 1_0_Rev0 | 1_0_Rev0 | 1_0_Rev0
1_0_Rev0 | 1_0_Rev0 | 1_0_Rev0 | 1_0_Rev0 | 1_0_Rev0 | 1_0_Rev0 | 1_0_Rev0
1_0_Rev0 | 1_0_Rev0 | 1_0_Rev0 | 1_0_Rev0 | 1_0_Rev0 | 1_0_Rev0 | 1_0_Rev0
Batteriefach | x 1

BT101

Batteriefach | x 1
| BT101
Batteriefach | x 1
| | BT101
Batteriefach | x 1
| | | BT101
Batteriefach | x 1
| | | | BT101
Batteriefach | x 1
| | | | | BT101
Batteriefach | x 1
| | | | | | BT101
470nF (474) | x 1

C801

470nF (474) | x 1
| C801
470nF (474) | x 1
| | C801
470nF (474) | x 1
| | | C801
470nF (474) | x 1
| | | | C801
470nF (474) | x 1
| | | | | C801
470nF (474) | x 1
| | | | | | C801
10µF (106) | x 4
C101, C306,
C401, C701
10µF (106) | x 4
| C101, C306, C401, C701
10µF (106) | x 4
| | C101, C306, C401, C701
10µF (106) | x 4
| | | C101, C306, C401, C701
10µF (106) | x 4
| | | | C101, C306, C401, C701
10µF (106) | x 4
| | | | | C101, C306, C401, C701
10µF (106) | x 4
| | | | | | C101, C306, C401, C701
100nF (104) | x 6
C204, C205, C302,
C303, C402, C604
100nF (104) | x 6
| C204, C205, C302, C303, C402, C604
100nF (104) | x 6
| | C204, C205, C302, C303, C402, C604
100nF (104) | x 6
| | | C204, C205, C302, C303, C402, C604
100nF (104) | x 6
| | | | C204, C205, C302, C303, C402, C604
100nF (104) | x 6
| | | | | C204, C205, C302, C303, C402, C604
100nF (104) | x 6
| | | | | | C204, C205, C302, C303, C402, C604
4.7nF (472) | x 2

C601, C602

4.7nF (472) | x 2
| C601, C602
4.7nF (472) | x 2
| | C601, C602
4.7nF (472) | x 2
| | | C601, C602
4.7nF (472) | x 2
| | | | C601, C602
4.7nF (472) | x 2
| | | | | C601, C602
4.7nF (472) | x 2
| | | | | | C601, C602
100µF Elko | x 2

C305, C702

100µF Elko | x 2
| C305, C702
100µF Elko | x 2
| | C305, C702
100µF Elko | x 2
| | | C305, C702
100µF Elko | x 2
| | | | C305, C702
100µF Elko | x 2
| | | | | C305, C702
100µF Elko | x 2
| | | | | | C305, C702
Schottkydiode | x 4
D201, D202,
D601, D602
Schottkydiode | x 4
| D201, D202, D601, D602
Schottkydiode | x 4
| | D201, D202, D601, D602
Schottkydiode | x 4
| | | D201, D202, D601, D602
Schottkydiode | x 4
| | | | D201, D202, D601, D602
Schottkydiode | x 4
| | | | | D201, D202, D601, D602
Schottkydiode | x 4
| | | | | | D201, D202, D601, D602

3.5mm AUX
Buchse vertikal

x 1

J301

| 3.5mm AUX Buchse vertikal
x 1

J301

| | 3.5mm AUX Buchse vertikal
x 1

J301

| | | 3.5mm AUX Buchse vertikal
x 1

J301

| | | | 3.5mm AUX Buchse vertikal
x 1

J301

| | | | | 3.5mm AUX Buchse vertikal
x 1

J301

| | | | | | 3.5mm AUX Buchse vertikal
x 1

J301
3.5mm AUX
Buchse horizontal

x 1

J701

| 3.5mm AUX Buchse horizontal
x 1

J701

| | 3.5mm AUX Buchse horizontal
x 1

J701

| | | 3.5mm AUX Buchse horizontal
x 1

J701

| | | | 3.5mm AUX Buchse horizontal
x 1

J701

| | | | | 3.5mm AUX Buchse horizontal
x 1

J701

| | | | | | 3.5mm AUX Buchse horizontal
x 1

J701
Kleinlautsprecher
x 1
LS701 | Kleinlautsprecher
x 1
| LS701 | Kleinlautsprecher
x 1
| | LS701 | Kleinlautsprecher
x 1
| | | LS701 | Kleinlautsprecher
x 1
| | | | LS701 | Kleinlautsprecher
x 1
| | | | | LS701 | Kleinlautsprecher
x 1
| | | | | | LS701
NPN Transistor x 1 Q201 | NPN Transistor x 1
| Q201 | NPN Transistor x 1
| | Q201 | NPN Transistor x 1
| | | Q201 | NPN Transistor x 1
| | | | Q201 | NPN Transistor x 1
| | | | | Q201 | NPN Transistor x 1
| | | | | | Q201

NPN Transistor
high beta

x 1
Q701 | NPN Transistor high beta

x 1
| Q701 | NPN Transistor high beta

x 1
| | Q701 | NPN Transistor high beta

x 1
| | | Q701 | NPN Transistor high beta

x 1
| | | | Q701 | NPN Transistor high beta

x 1
| | | | | Q701 | NPN Transistor high beta

x 1

| | | | | | Q701

PNP Transistor
high beta

x 1
Q702 | PNP Transistor high beta

x 1
| Q702 | PNP Transistor high beta

x 1
| | Q702 | PNP Transistor high beta

x 1
| | | Q702 | PNP Transistor high beta

x 1
| | | | Q702 | PNP Transistor high beta

x 1
| | | | | Q702 | PNP Transistor high beta

x 1

| | | | | | Q702
6.8kΩ | x 4
R202, R206,
R331, R332
6.8kΩ | x 4
| R202, R206, R331, R332
6.8kΩ | x 4
| | R202, R206, R331, R332
6.8kΩ | x 4
| | | R202, R206, R331, R332
6.8kΩ | x 4
| | | | R202, R206, R331, R332
6.8kΩ | x 4
| | | | | R202, R206, R331, R332
6.8kΩ | x 4
| | | | | | R202, R206, R331, R332
1MΩ | x 2
R203, R703
1MΩ | x 2
| R203, R703
1MΩ | x 2
| | R203, R703
1MΩ | x 2
| | | R203, R703
1MΩ | x 2
| | | | R203, R703
1MΩ | x 2
| | | | | R203, R703
1MΩ | x 2
| | | | | | R203, R703
1.5kΩ | x 25
R201, R204, R205, R302-R307, R321, R403, R404, R502-R504, R601, R602, R606-R609, R704-R707
1.5kΩ | x 25
| R201, R204, R205, R302-R307, R321, R403, R404, R502-R504, R601, R602, R606-R609, R704-R707
1.5kΩ | x 25
| | R201, R204, R205, R302-R307, R321, R403, R404, R502-R504, R601, R602, R606-R609, R704-R707
1.5kΩ | x 25
| | | R201, R204, R205, R302-R307, R321, R403, R404, R502-R504, R601, R602, R606-R609, R704-R707
1.5kΩ | x 25
| | | | R201, R204, R205, R302-R307, R321, R403, R404, R502-R504, R601, R602, R606-R609, R704-R707
1.5kΩ | x 25
| | | | | R201, R204, R205, R302-R307, R321, R403, R404, R502-R504, R601, R602, R606-R609, R704-R707
1.5kΩ | x 25
| | | | | | R201, R204, R205, R302-R307, R321, R403, R404, R502-R504, R601, R602, R606-R609, R704-R707

330Ω | x 1

R308

330Ω | x 1

R308

330Ω | x 1

R308

330Ω | x 1

R308

330Ω | x 1

R308

330Ω | x 1

R308

330Ω | x 1

R308

402Ω | x 1

R309

402Ω | x 1

R309

402Ω | x 1

R309

402Ω | x 1

R309

402Ω | x 1

R309

402Ω | x 1

R309

402Ω | x 1

R309

442Ω | x 1

R310

442Ω | x 1

R310

442Ω | x 1

R310

442Ω | x 1

R310

442Ω | x 1

R310

442Ω | x 1

R310

442Ω | x 1

R310

536Ω | x 1

R311

536Ω | x 1

R311

536Ω | x 1

R311

536Ω | x 1

R311

536Ω | x 1

R311

536Ω | x 1

R311

536Ω | x 1

R311

619Ω | x 1

R312

619Ω | x 1

R312

619Ω | x 1

R312

619Ω | x 1

R312

619Ω | x 1

R312

619Ω | x 1

R312

619Ω | x 1

R312

698Ω | x 1

R313

698Ω | x 1

R313

698Ω | x 1

R313

698Ω | x 1

R313

698Ω | x 1

R313

698Ω | x 1

R313

698Ω | x 1

R313

787Ω | x 1

R314

787Ω | x 1

R314

787Ω | x 1

R314

787Ω | x 1

R314

787Ω | x 1

R314

787Ω | x 1

R314

787Ω | x 1

R314

910Ω | x 1

R315

910Ω | x 1

R315

910Ω | x 1

R315

910Ω | x 1

R315

910Ω | x 1

R315

910Ω | x 1

R315

910Ω | x 1

R315

1.05kΩ | x 1

R316

1.05kΩ | x 1

R316

1.05kΩ | x 1

R316

1.05kΩ | x 1

R316

1.05kΩ | x 1

R316

1.05kΩ | x 1

R316

1.05kΩ | x 1

R316

1.21kΩ | x 1

R317

1.21kΩ | x 1

R317

1.21kΩ | x 1

R317

1.21kΩ | x 1

R317

1.21kΩ | x 1

R317

1.21kΩ | x 1

R317

1.21kΩ | x 1

R317
1.33kΩ | x 1

R318

1.33kΩ | x 1

R318

1.33kΩ | x 1

R318

1.33kΩ | x 1

R318

1.33kΩ | x 1

R318

1.33kΩ | x 1

R318

1.33kΩ | x 1

R318

10kΩ | x 6
R401, R402, R501,
R604, R605, R708
10kΩ | x 6
R401, R402, R501,
R604, R605, R708
10kΩ | x 6
R401, R402, R501,
R604, R605, R708
10kΩ | x 6
R401, R402, R501,
R604, R605, R708
10kΩ | x 6
R401, R402, R501,
R604, R605, R708

10kΩ
R401, R402, R501,
R604, R605, R708
10kΩ | x 6
R401, R402, R501,
R604, R605, R708
3.5kΩ | x 1
R603
3.5kΩ | x 1
R603
3.5kΩ | x 1
R603
3.5kΩ | x 1
R603
3.5kΩ | x 1
R603
3.5kΩ | x 1
R603
3.5kΩ | x 1
R603
47kΩ | x 2
R320, R701
47kΩ | x 2
R320, R701
47kΩ | x 2
R320, R701
47kΩ | x 2
R320, R701
47kΩ | x 2
R320, R701
47kΩ | x 2
R320, R701
47kΩ | x 2
R320, R701
100Ω | x 3

R319, R702, R710

100Ω | x 3

R319, R702, R710

100Ω | x 3

R319, R702, R710

100Ω | x 3

R319, R702, R710

100Ω | x 3

R319, R702, R710

100Ω | x 3

R319, R702, R710

100Ω | x 3

R319, R702, R710

10kΩ_lin | x 6
RV201, RV303, RV501,
RV602, RV701, RV801
10kΩ_lin | x 6
RV201, RV303, RV501,
RV602, RV701, RV801
10kΩ_lin | x 6
RV201, RV303, RV501,
RV602, RV701, RV801
10kΩ_lin | x 6
RV201, RV303, RV501,
RV602, RV701, RV801
10kΩ_lin | x 6
RV201, RV303, RV501,
RV602, RV701, RV801
10kΩ_lin | x 6
RV201, RV303, RV501,
RV602, RV701, RV801
10kΩ_lin | x 6
RV201, RV303, RV501,
RV602, RV701, RV801
5kΩ_trim | x 2
RV301, RV302
5kΩ_trim | x 2
RV301, RV302
5kΩ_trim | x 2
RV301, RV302
5kΩ_trim | x 2
RV301, RV302
5kΩ_trim | x 2
RV301, RV302
5kΩ_trim | x 2
RV301, RV302
5kΩ_trim | x 2
RV301, RV302

50kΩ_log_stereo
x 1
RV601

50kΩ_log_stereo
x 1
RV601

50kΩ_log_stereo
x 1
RV601

50kΩ_log_stereo
x 1
RV601

50kΩ_log_stereo
x 1
RV601

50kΩ_log_stereo
x 1
RV601

50kΩ_log_stereo
x 1
RV601

Druckknopf
x 1
SW301

Druckknopf
x 1
SW301

Druckknopf
x 1
SW301

Druckknopf
x 1
SW301

Druckknopf
x 1
SW301

Druckknopf
x 1
SW301

Druckknopf
x 1
SW301

Schiebeschalter x 2

SW101, SW302

Schiebeschalter x 2

SW101, SW302

Schiebeschalter x 2

SW101, SW302

Schiebeschalter x 2

SW101, SW302

Schiebeschalter x 2

SW101, SW302

Schiebeschalter x 2

SW101, SW302

Schiebeschalter x 2

SW101, SW302

DIP-Schalter x 1

SW801

DIP-Schalter x 1

SW801

DIP-Schalter x 1

SW801

DIP-Schalter x 1

SW801

DIP-Schalter x 1

SW801

DIP-Schalter x 1

SW801

DIP-Schalter x 1

SW801

MCP6004 | x 2

U1, U2

Sockel zuerst löten und
Polarität achten!
MCP6004 | x 2
| U1, U2

Sockel zuerst löten und
Polarität achten!
MCP6004 | x 2
| U1, U2

Sockel zuerst löten und
Polarität achten!
MCP6004 | x 2
| U1, U2

Sockel zuerst löten und
Polarität achten!
MCP6004 | x 2
| U1, U2

Sockel zuerst löten und
Polarität achten!
MCP6004 | x 2
| U1, U2

Sockel zuerst löten und
Polarität achten!
MCP6004 | x 2
| U1, U2

Sockel zuerst löten und
Polarität achten!
IC-Sockel | x 2

U1, U2

Polarität beachten!

IC-Sockel | x 2

U1, U2

Polarität beachten!

IC-Sockel | x 2

U1, U2

Polarität beachten!

IC-Sockel | x 2

U1, U2

Polarität beachten!

IC-Sockel | x 2

U1, U2

Polarität beachten!

IC-Sockel | x 2

U1, U2

Polarität beachten!

IC-Sockel | x 2

U1, U2

Polarität beachten!

MCP6002 | x 1
| U3

Sockel zuerst löten und
Polarität achten!
MCP6002 | x 1
| U3

Sockel zuerst löten und
Polarität achten!
MCP6002 | x 1
| U3

Sockel zuerst löten und
Polarität achten!
MCP6002 | x 1
| U3

Sockel zuerst löten und
Polarität achten!
MCP6002 | x 1
| U3

Sockel zuerst löten und
Polarität achten!
MCP6002 | x 1
| U3

Sockel zuerst löten und
Polarität achten!
MCP6002 | x 1
| U3

Sockel zuerst löten und
Polarität achten!
NE555 | x 1
| U201

Sockel zuerst löten und
Polarität achten!
NE555 | x 1
| U201

Sockel zuerst löten und
Polarität achten!
NE555 | x 1
| U201

Sockel zuerst löten und
Polarität achten!
NE555 | x 1
| U201

Sockel zuerst löten und
Polarität achten!
NE555 | x 1
| U201

Sockel zuerst löten und
Polarität achten!
NE555 | x 1
| U201

Sockel zuerst löten und
Polarität achten!
NE555 | x 1
| U201

Sockel zuerst löten und
Polarität achten!

IC-Sockel x8 x 1

U201, U3

Polarität beachten!

IC-Sockel x8 x 1

U201, U3

Polarität beachten!

IC-Sockel x8 x 1

U201, U3

Polarität beachten!

IC-Sockel x8 x 1

U201, U3

Polarität beachten!

IC-Sockel x8 x 1

U201, U3

Polarität beachten!

IC-Sockel x8 x 1

U201, U3

Polarität beachten!

IC-Sockel x8 x 1

U201, U3

Polarität beachten!

Platinenfüße x 5
jeweils i.d. Ecken
und i.d. Mitte

Platinenfüße x 5
jeweils i.d. Ecken
und i.d. Mitte

Platinenfüße x 5
jeweils i.d. Ecken
und i.d. Mitte

Platinenfüße x 5
jeweils i.d. Ecken
und i.d. Mitte

Platinenfüße x 5
jeweils i.d. Ecken
und i.d. Mitte

Platinenfüße x 5
jeweils i.d. Ecken
und i.d. Mitte

Platinenfüße x 5
jeweils i.d. Ecken
und i.d. Mitte

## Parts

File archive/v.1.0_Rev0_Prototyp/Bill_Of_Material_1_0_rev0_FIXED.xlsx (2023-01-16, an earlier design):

Drone o Tron v_1_0 Rev0 FIXED |  | für 1 DOT
BT101 | Batteriefach | 1
> C1, C801 | 470nF | 2
> C101, C306, C401, C701 | 10µF | 4
> C204, C205, C302, C303, C402, C604 | 100nF | 6
> C601, C602 | 4.7nF | 2
> C305, C702 | 100µF | 2
> D201, D202, D601, D602 | Schottkydiode | 4
J301 | 3.5mm_AUX_plug/buchse_PJ392_vertical | 1
J701 | AudioJack3_SwitchTR | 1
LS701 | Speaker_Lautsprecher | 1
Q201 | NPN-BJT/Bipo | 1
Q701 | NPN-BJT/Bipo_high_beta | 1
Q702 | PNP-BJT/Bipo_high_beta | 1
> R202, R206, R331, R332 | 6.8kΩ | 4
> R203, R703 | 1MΩ | 2
> R201, R204, R205, R302-R307, R321, R403, R404, R502-R504, R601, R602, R606-R609, R704-R707 | 1.5kΩ | 25
R308 | 330Ω | 1
R309 | 402Ω | 1
R310 | 442Ω | 1
R311 | 536Ω | 1
R312 | 619Ω | 1
R313 | 698Ω | 1
R314 | 787Ω | 1
R315 | 910Ω | 1
R316 | 1.05kΩ | 1
R317 | 1.21kΩ | 1
R318 | 1.33kΩ | 1
> R401, R402, R501, R604, R605, R708 | 10kΩ | 6
R603 | 3.5kΩ | 1
> R320, R701 | 47kΩ | 2
> R319, R702, R710 | 100Ω | 3
> RV201, RV303, RV501, RV602, RV701, RV801 | 10kΩ_lin | 6
> RV301, RV302 | 5kΩ_trim | 2
RV601 | 50kΩ_log_stereo | 1
SW301 | push_button/Knopf | 1
> SW101, SW302 | slider_switch/schiebeschalter | 2
SW801 | DIP_switch | 1
> U1, U2 | MCP6004 | 2
U3 | MCP6002 | 1
U201 | NE555 | 1
 | Platinenfüße | 5
 | M3 Schraube + Mutter | 2
 | Sockel DIP 8 | 2
 | Sockel DIP 14 | 2
 | Mono Aux Kabel | 1
 | AAA Batterie | 2
 | Platine v_1_0Rev0 | 1

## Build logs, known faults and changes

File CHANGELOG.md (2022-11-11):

# Changelog
All notable changes to this project are relative to the preversion and will be documented in this file.

---

## [released]
## [1.0.0.Rev0] - 2022-11-07

### Added - due to the many improvements relative to the previous version only functional changes are roughly listed
- added PCB-board design with the size of 100*168.1mm with exclusive artworks and logos from myself
- added slider switch to turn on/off the circuit
- added keyboard with well tempered calibration for the NE555-VCO, freely controllable frequency range over two potentiometers
- added a octaver switch to toggle between two octaves
- added a drone mode to freely control the pitch over a potentiometer
- added toggle switch to imitate the function of a forte-switch of a piano. If turned on the note will be hold unless the release button gets pressed
- added a portamento potentiometer to control the full-settlement-transition time between to notes from zero to around five seconds
- added an output stage with volume knob and a power amplifier for an onboard speaker and a switched headphone jack, which turns of the speaker if plugged in
- added a battery holder as voltage source for on the go use and many hours of possible playtime
- added input resistors to all opamp inputs to limit the inrush current to the MOSFET gate input capacitances 

---

## [Unreleased]
## [0.2.0] - 2022-10-07

### Changed - indexes used are from v0.2
- changed opamps to MCP6004 and MCP6002 as low power, low voltage, rail-to-rail, MOSFET-input opamps
- changed R102 from 10kΩ to 7kΩ for wider duty-cycle range
- changed C201 from 20nF to 1µF for lower pitch
- changed C202 from 100nF to 22nF for lower influence to the pitch
- changed R203 from 10kΩ to 1MΩ for pushing the cutoff of the high-pass filter down
- changed R501 from 2kΩ to 10kΩ for -21dB attenuation for equal perceived loudness of triangle and rectangle
- changed RV501 to logarithmic scale for exponential sweep from triangle to rectangle
- changed RV601 to logarithmic scale for organic sweep in frequency cutoff

### Added - indexes used are from v0.2
- added pull down resistor R301 due to input capacity of the opamp
- added buffer cap C401 for stability of VDD/2
- added clipped non-inverting amplifier to feedback of the main filter for limited feedback and sound improvement
- added whole power amplifier and line-out section (section 7xx) with volume knob, a small power amplifier for a small on-board speaker and buffered line-out with nominal output impedance

### Removed
- pulldown resistor R31

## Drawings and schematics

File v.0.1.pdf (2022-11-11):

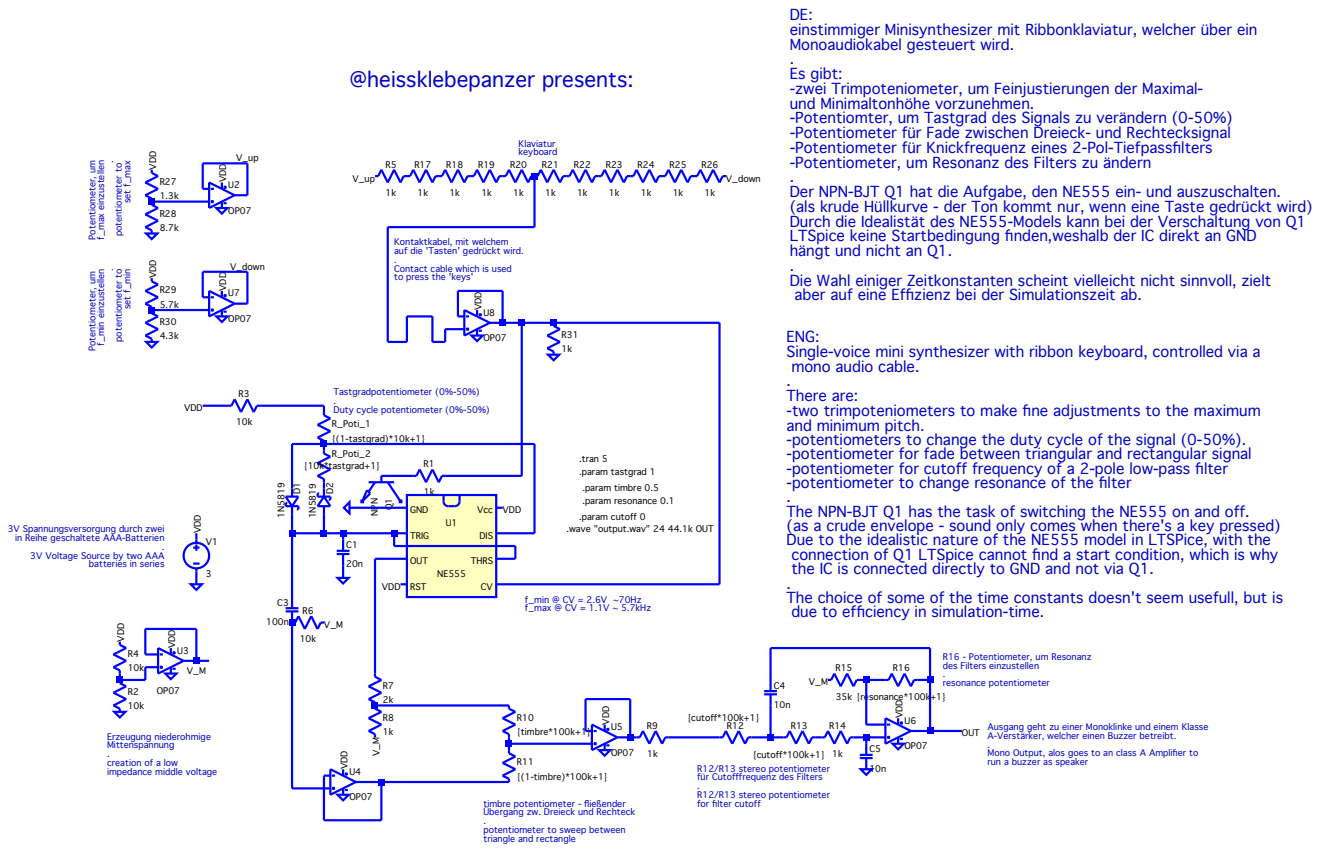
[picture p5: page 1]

einstimmiger Minisynthesizer mit Ribbonklaviatur, welcher über ein
Monoaudiokabel gesteuert wird.
Es gibt:
-zwei Trimpoteniometer, um Feinjustierungen der Maximal-
und Minimaltonhöhe vorzunehmen.
-Potentiomter, um Tastgrad des Signals zu verändern (0-50%)
-Potentiometer für Fade zwischen Dreieck- und Rechtecksignal
-Potentiometer für Knickfrequenz eines 2-Pol-Tiefpassfilters
-Potentiometer, um Resonanz des Filters zu ändern
Der NPN-BJT Q1 hat die Aufgabe, den NE555 ein- und auszuschalten.

mu,r ete moi tnet oP nell etsuzni e xa m_f

ot r ete moi tnet op xa m_f tes

(als krude Hüllkurve - der Ton kommt nur, wenn eine Taste gedrückt wird)
Durch die Idealistät des NE555-Models kann bei der Verschaltung von Q1
LTSpice keine Startbedingung finden,weshalb der IC direkt an GND
hängt und nicht an Q1.
Die Wahl einiger Zeitkonstanten scheint vielleicht nicht sinnvoll, zielt
aber auf eine Effizienz bei der Simulationszeit ab.

Kontaktkabel, mit welchem
auf die 'Tasten' gedrückt wird.

Contact cable which is used m
to press the 'keys' u,r ete moi tnet oP nell etsuzni e ni m_f

ot r ete moi tnet op ni m_f tes

ENG:
Single-voice mini synthesizer with ribbon keyboard, controlled via a
mono audio cable.
There are:
-two trimpoteniometers to make fine adjustments to the maximum
and minimum pitch.
-potentiometers to change the duty cycle of the signal (0-50%).
-potentiometer for fade between triangular and rectangular signal
-potentiometer for cutoff frequency of a 2-pole low-pass filter
-potentiometer to change resonance of the filter .
The NPN-BJT Q1 has the task of switching the NE555 on and off.
(as a crude envelope - sound only comes when there's a key pressed)
Due to the idealistic nature of the NE555 model in LTSPice, with the
connection of Q1 LTSpice cannot find a start condition, which is why the IC is connected directly to GND and not via Q1.
The choice of some of the time constants doesn't seem usefull, but is

.tran 5
.param tastgrad 1
.param timbre 0.5
.param resonance 0.1
.param cutoff 0
.wave "output.wav" 24 44.1k OUT

3V Spannungsversorgung durch zwei
in Reihe geschaltete AAA-Batterien
. 3V Voltage Source by two AAA

due to efficiency in simulation-time.

Ausgang geht zu einer Monoklinke und einem Klasse
OUT
A-Verstärker, welcher einen Buzzer betreibt.
Mono Output, alos goes to an class A Amplifier to
run a buzzer as speaker

R12/R13 stereo potentiometer
für Cutofffrequenz des Filters

Übergang zw. Dreieck und Rechteck
potentiometer to sweep between
triangle and rectangle

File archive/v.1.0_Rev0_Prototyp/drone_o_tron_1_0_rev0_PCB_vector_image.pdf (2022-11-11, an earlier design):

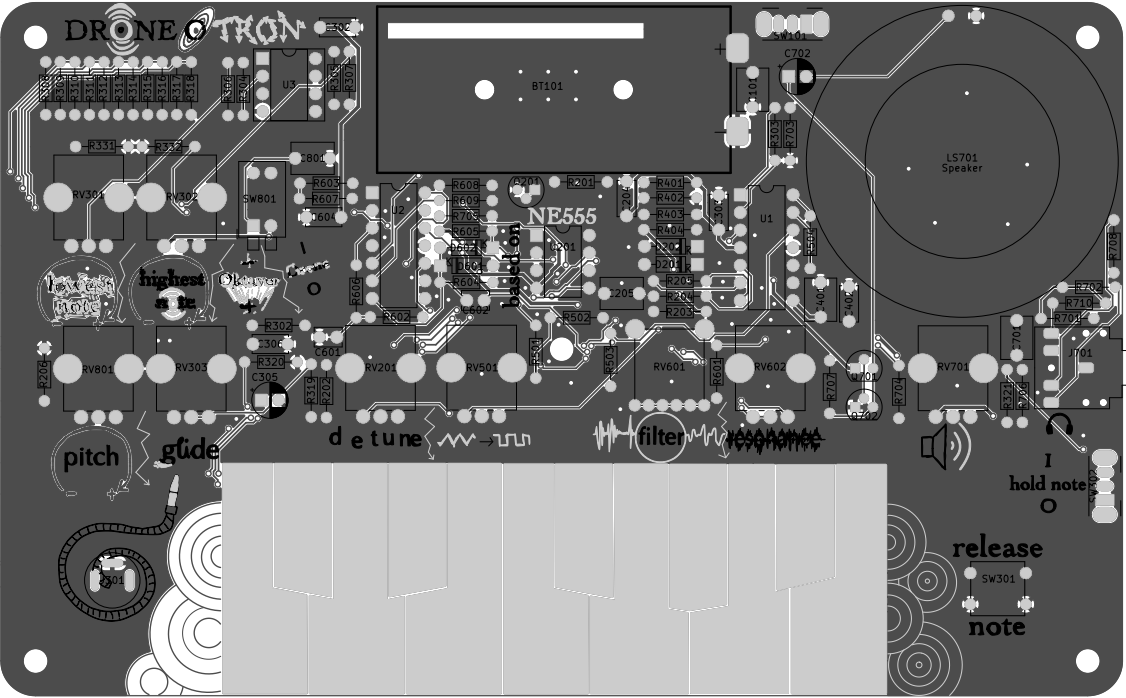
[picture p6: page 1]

Drone-O-Tron v.1.0, Rev 0 Dirtrand Paul Ranz @heissklebepanzer / heissklebepanzer.de / opensynthesizer.de

## ©Konrad Dirk Paul Panzer, 2022

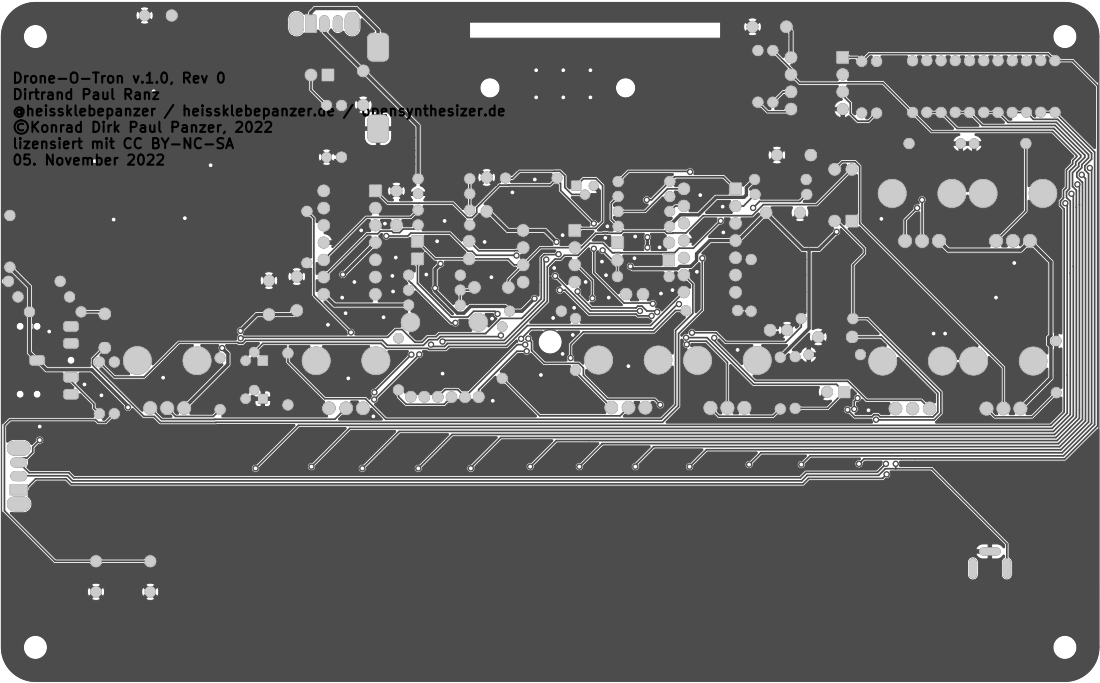
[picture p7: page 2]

lizensiert mit CC BY-NC-SA
05. November 2022

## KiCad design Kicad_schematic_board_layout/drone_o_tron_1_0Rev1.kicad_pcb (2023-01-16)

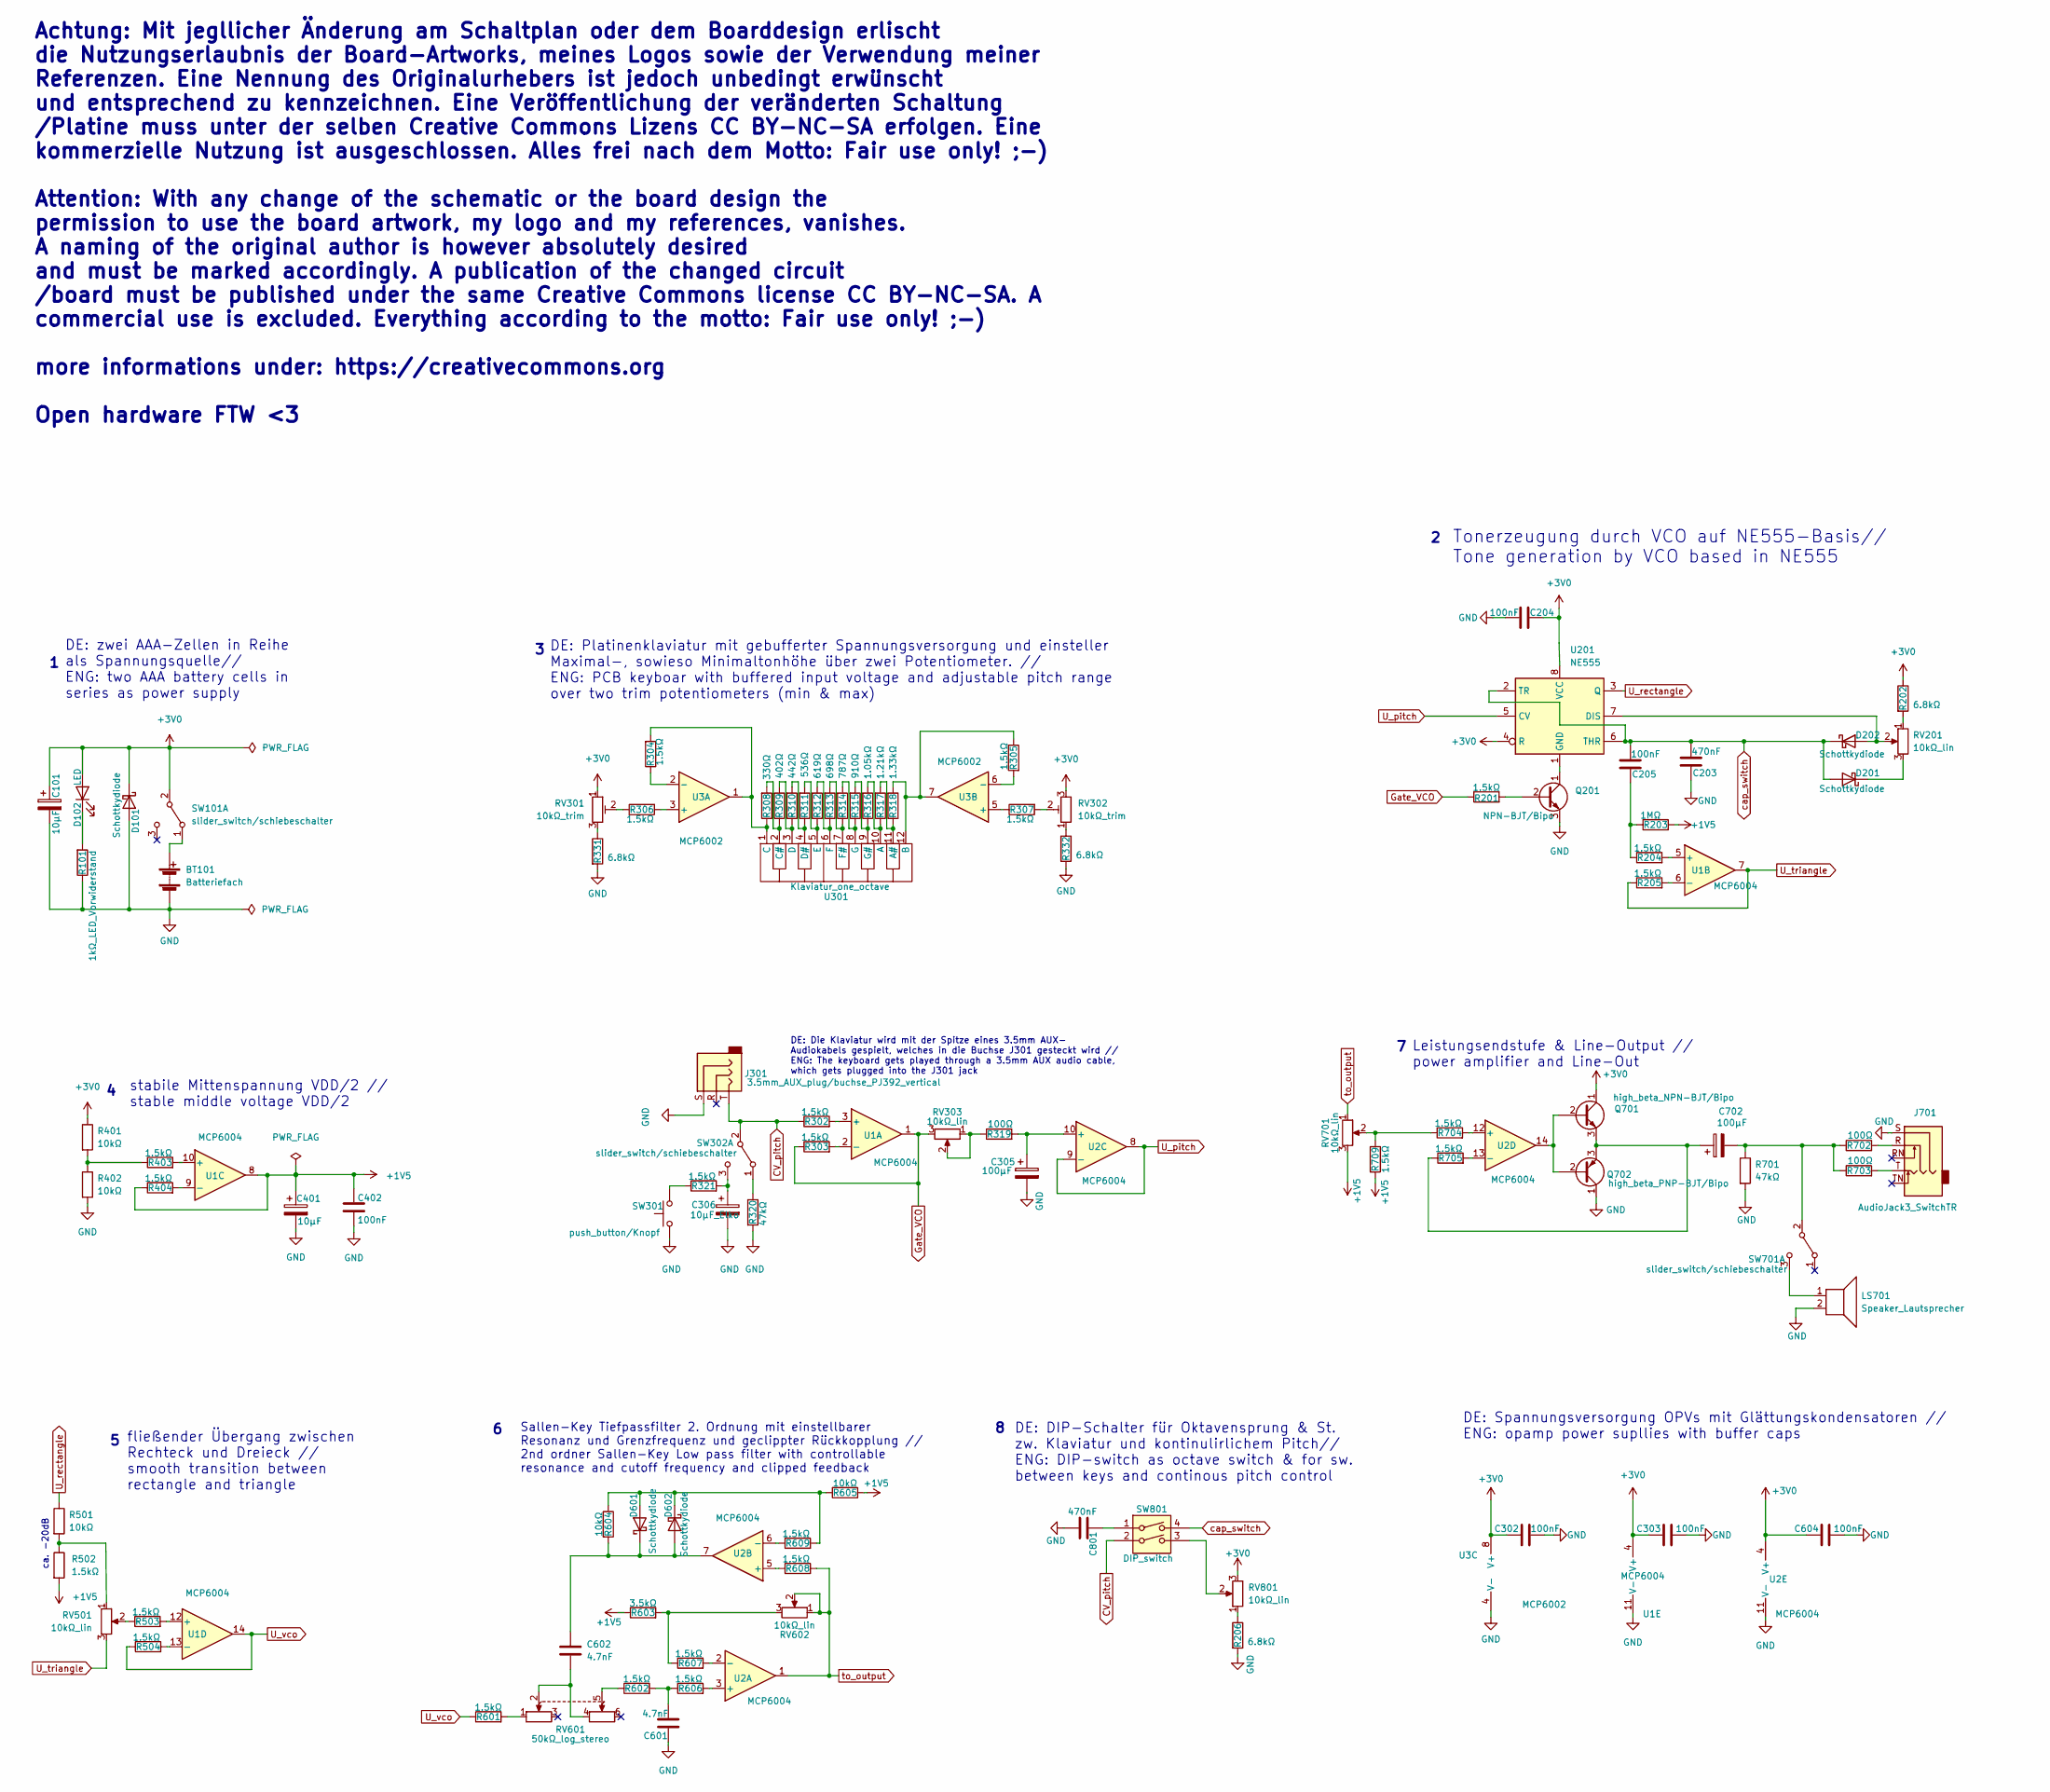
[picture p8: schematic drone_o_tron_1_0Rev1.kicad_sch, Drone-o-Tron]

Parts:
BT101: Batteriefach; Reichelt_Batteriehalter_2_AAA
C101, C401: 10µF; C_Disc_D6.0mm_W4.4mm_P5.00mm
C203, C801: 470nF; C_Disc_D6.0mm_W4.4mm_P5.00mm
C204, C302, C303, C402, C604: 100nF; C_Disc_D5.0mm_W2.5mm_P5.00mm
C205: 100nF; C_Disc_D6.0mm_W2.5mm_P5.00mm
C305, C702: 100µF; CP_Radial_D5.0mm_P2.50mm
C306: 10µF_Elko; CP_Radial_D5.0mm_P2.00mm
C601, C602: 4.7nF; C_Disc_D3.8mm_W2.6mm_P2.50mm
D101, D201, D202, D601, D602: Schottkydiode; D_DO-35_SOD27_P7.62mm_Horizontal
D102: LED; LED_D3.0mm_Clear
J301: 3.5mm_AUX_plug/buchse_PJ392_vertical; PJ-392
J701: AudioJack3_SwitchTR; Audio_Jack_stereo_tip_ring_switch_PJ-307
LS701: Speaker_Lautsprecher; speaker_LSM-45F
Q201: NPN-BJT/Bipo; TO-92
Q701: high_beta_NPN-BJT/Bipo; TO-92
Q702: high_beta_PNP-BJT/Bipo; TO-92
R101: 1kΩ_LED_Vorwiderstand; R_Axial_DIN0204_L3.6mm_D1.6mm_P7.62mm_Horizontal
R201, R204, R205, R302, R303, R304, R305, R306, R307, R321, R403, R404, R502, R503, R504, R601, R602, R606, R607, R608, R609, R704, R705, R709: 1.5kΩ; R_Axial_DIN0204_L3.6mm_D1.6mm_P7.62mm_Horizontal
R202, R206, R331, R332: 6.8kΩ; R_Axial_DIN0204_L3.6mm_D1.6mm_P7.62mm_Horizontal
R203: 1MΩ; R_Axial_DIN0204_L3.6mm_D1.6mm_P7.62mm_Horizontal
R308: 330Ω; R_Axial_DIN0204_L3.6mm_D1.6mm_P7.62mm_Horizontal
R309: 402Ω; R_Axial_DIN0204_L3.6mm_D1.6mm_P7.62mm_Horizontal
R310: 442Ω; R_Axial_DIN0204_L3.6mm_D1.6mm_P7.62mm_Horizontal
R311: 536Ω; R_Axial_DIN0204_L3.6mm_D1.6mm_P7.62mm_Horizontal
R312: 619Ω; R_Axial_DIN0204_L3.6mm_D1.6mm_P7.62mm_Horizontal
R313: 698Ω; R_Axial_DIN0204_L3.6mm_D1.6mm_P7.62mm_Horizontal
R314: 787Ω; R_Axial_DIN0204_L3.6mm_D1.6mm_P7.62mm_Horizontal
R315: 910Ω; R_Axial_DIN0204_L3.6mm_D1.6mm_P7.62mm_Horizontal
R316: 1.05kΩ; R_Axial_DIN0204_L3.6mm_D1.6mm_P7.62mm_Horizontal
R317: 1.21kΩ; R_Axial_DIN0204_L3.6mm_D1.6mm_P7.62mm_Horizontal
R318: 1.33kΩ; R_Axial_DIN0204_L3.6mm_D1.6mm_P7.62mm_Horizontal
R319, R702, R703: 100Ω; R_Axial_DIN0204_L3.6mm_D1.6mm_P7.62mm_Horizontal
R320, R701: 47kΩ; R_Axial_DIN0204_L3.6mm_D1.6mm_P7.62mm_Horizontal
R401, R402, R501, R604, R605: 10kΩ; R_Axial_DIN0204_L3.6mm_D1.6mm_P7.62mm_Horizontal
R603: 3.5kΩ; R_Axial_DIN0204_L3.6mm_D1.6mm_P7.62mm_Horizontal
RV201, RV303, RV501, RV602, RV701, RV801: 10kΩ_lin; Potentiometer_Alps_RK09K_Single_Vertical
RV301, RV302: 10kΩ_trim; Potentiometer_Bourns_3296X_Horizontal
RV601: 50kΩ_log_stereo; rk_12L12_stereo_potentiometer
SW101, SW302, SW701: slider_switch/schiebeschalter; SW_CuK_OS102011MA1QN1_SPDT_Angled
SW301: push_button/Knopf; push_button_8mm
SW801: DIP_switch; SW_DIP_SPSTx02_Slide_6.7x6.64mm_W7.62mm_P2.54mm_LowProfile
U1, U2: MCP6004; DIP-14_W7.62mm
U3: MCP6002; DIP-8_W7.62mm_Socket
U201: NE555; DIP-8_W7.62mm
U301: Klaviatur_one_octave; PCB_piano_keys_1_ocatve_100mm

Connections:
+1V5: C401.1, C402.1, R203.2, R404.1, R502.2, R603.1, R605.1, R709.2, RV701.3, U1.8
+3V0: C101.1, C204.2, C302.1, C303.1, C604.1, D101.1 (K), D102.2 (A), Q701.1 (C), R202.1, R401.1, RV301.1, RV302.3, RV801.3, SW101.2 (B), U1.4 (V+), U2.4 (V+), U3.8 (V+), U201.4 (R), U201.8 (VCC)
CV_pitch: J301.T, R302.1, SW302.2 (B), SW801.2
GND: BT101.2 (-), C101.2, C203.1, C204.1, C302.2, C303.2, C305.2, C306.2, C401.2, C402.2, C601.2, C604.2, C801.2, D101.2 (A), J301.S, J701.S, LS701.2, Q201.3 (E), Q702.1 (C), R101.1, R206.2, R320.2, R331.2, R332.2, R402.2, R701.2, SW301.1 (A), SW301.2 (A), U1.11 (V-), U2.11 (V-), U3.4 (V-)
Gate_VCO: R201.1, R303.1, RV303.3, U1.1
unnamed: BT101.1 (+), SW101.1 (A)
unnamed: C205.1, R203.1, R204.1
unnamed: C305.1, R319.2, U2.10 (+)
unnamed: C306.1, R321.2, SW302.3 (C)
unnamed: C601.1, R602.2, R606.1
unnamed: C602.1, D601.1 (K), D602.2 (A), R604.2, U2.7
unnamed: C602.2, RV601.2, RV601.4
unnamed: C702.1, Q701.3 (E), Q702.3 (E), R705.1
unnamed: C702.2, R701.1, R702.1, R703.1, SW701.2 (B)
unnamed: C801.1, SW801.1
unnamed: D102.1 (K), R101.2
unnamed: D201.1 (K), RV201.3
unnamed: D202.2 (A), RV201.2, U201.7 (DIS)
unnamed: D601.2 (A), D602.1 (K), R604.1, R605.2, R609.2
unnamed: J701.R, R702.2
unnamed: J701.T, R703.2
unnamed: LS701.1, SW701.3 (C)
unnamed: Q201.1 (C), U201.1 (GND)
unnamed: Q201.2 (B), R201.2
unnamed: Q701.2 (B), Q702.2 (B), U2.14
unnamed: R202.2, RV201.1
unnamed: R204.2, U1.5 (+)
unnamed: R205.2, U1.6 (-)
unnamed: R206.1, RV801.1
unnamed: R302.2, U1.3 (+)
unnamed: R303.2, U1.2 (-)
unnamed: R304.1, U3.2 (-)
unnamed: R304.2, R308.1, U3.1, U301.1 (C)
unnamed: R305.1, R318.2, U3.7, U301.12 (B)
unnamed: R305.2, U3.6 (-)
unnamed: R306.1, RV301.2
unnamed: R306.2, U3.3 (+)
unnamed: R307.1, U3.5 (+)
unnamed: R307.2, RV302.2
unnamed: R308.2, R309.1, U301.2 (C#)
unnamed: R309.2, R310.1, U301.3 (D)
unnamed: R310.2, R311.1, U301.4 (D#)
unnamed: R311.2, R312.1, U301.5 (E)
unnamed: R312.2, R313.1, U301.6 (F)
unnamed: R313.2, R314.1, U301.7 (F#)
unnamed: R314.2, R315.1, U301.8 (G)
unnamed: R315.2, R316.1, U301.9 (G#)
unnamed: R316.2, R317.1, U301.10 (A)
unnamed: R317.2, R318.1, U301.11 (A#)
unnamed: R319.1, RV303.1, RV303.2
unnamed: R320.1, SW302.1 (A)
unnamed: R321.1, SW301.3 (B), SW301.4 (B)
unnamed: R331.1, RV301.3
unnamed: R332.1, RV302.1
unnamed: R401.2, R402.1, R403.1
unnamed: R403.2, U1.10 (+)
unnamed: R404.2, U1.9 (-)
unnamed: R501.2, R502.1, RV501.1
unnamed: R503.1, RV501.2
unnamed: R503.2, U1.12 (+)
unnamed: R504.2, U1.13 (-)
unnamed: R601.2, RV601.1
unnamed: R602.1, RV601.5
unnamed: R603.2, R607.1, RV602.3
unnamed: R606.2, U2.3 (+)
unnamed: R607.2, U2.2 (-)
unnamed: R608.1, U2.5 (+)
unnamed: R609.1, U2.6 (-)
unnamed: R704.1, R709.1, RV701.2
unnamed: R704.2, U2.12 (+)
unnamed: R705.2, U2.13 (-)
unnamed: RV801.2, SW801.3
U_pitch: U2.8, U2.9 (-), U201.5 (CV)
U_rectangle: R501.1, U201.3 (Q)
U_triangle: R205.1, RV501.3, U1.7
U_vco: R504.1, R601.1, U1.14
cap_switch: C203.2, C205.2, D201.2 (A), D202.1 (K), SW801.4, U201.2 (TR), U201.6 (THR)
to_output: R608.2, RV602.1, RV602.2, RV701.1, U2.1

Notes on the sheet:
ca. -20dB
DE: Platinenklaviatur mit gebufferter Spannungsversorgung und einsteller Maximal-, sowieso Minimaltonhöhe über zwei Potentiometer. // ENG: PCB keyboar with buffered input voltage and adjustable pitch range over two trim potentiometers (min & max)
DE: Spannungsversorgung OPVs mit Glättungskondensatoren // ENG: opamp power supllies with buffer caps
Tonerzeugung durch VCO auf NE555-Basis// Tone generation by VCO based in NE555
Sallen-Key Tiefpassfilter 2. Ordnung mit einstellbarer Resonanz und Grenzfrequenz und geclippter Rückkopplung // 2nd ordner Sallen-Key Low pass filter with controllable resonance and cutoff frequency and clipped feedback
fließender Übergang zwischen Rechteck und Dreieck // smooth transition between rectangle and triangle
stabile Mittenspannung VDD/2 // stable middle voltage VDD/2
DE: zwei AAA-Zellen in Reihe als Spannungsquelle// ENG: two AAA battery cells in series as power supply
DE: DIP-Schalter für Oktavensprung & St. zw. Klaviatur und kontinulirlichem Pitch// ENG: DIP-switch as octave switch & for sw. between keys and continous pitch control
Leistungsendstufe & Line-Output // power amplifier and Line-Out
Achtung: Mit jegllicher Änderung am Schaltplan oder dem Boarddesign erlischt die Nutzungserlaubnis der Board-Artworks, meines Logos sowie der Verwendung meiner Referenzen. Eine Nennung des Originalurhebers ist jedoch unbedingt erwünscht und entsprechend zu kennzeichnen. Eine Veröffentlichung der ve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
DE: Die Klaviatur wird mit der Spitze eines 3.5mm AUX- Audiokabels gespielt, welches in die Buchse J301 gesteckt wird // ENG: The keyboard gets played through a 3.5mm AUX audio cable, which gets plugged into the J301 jack

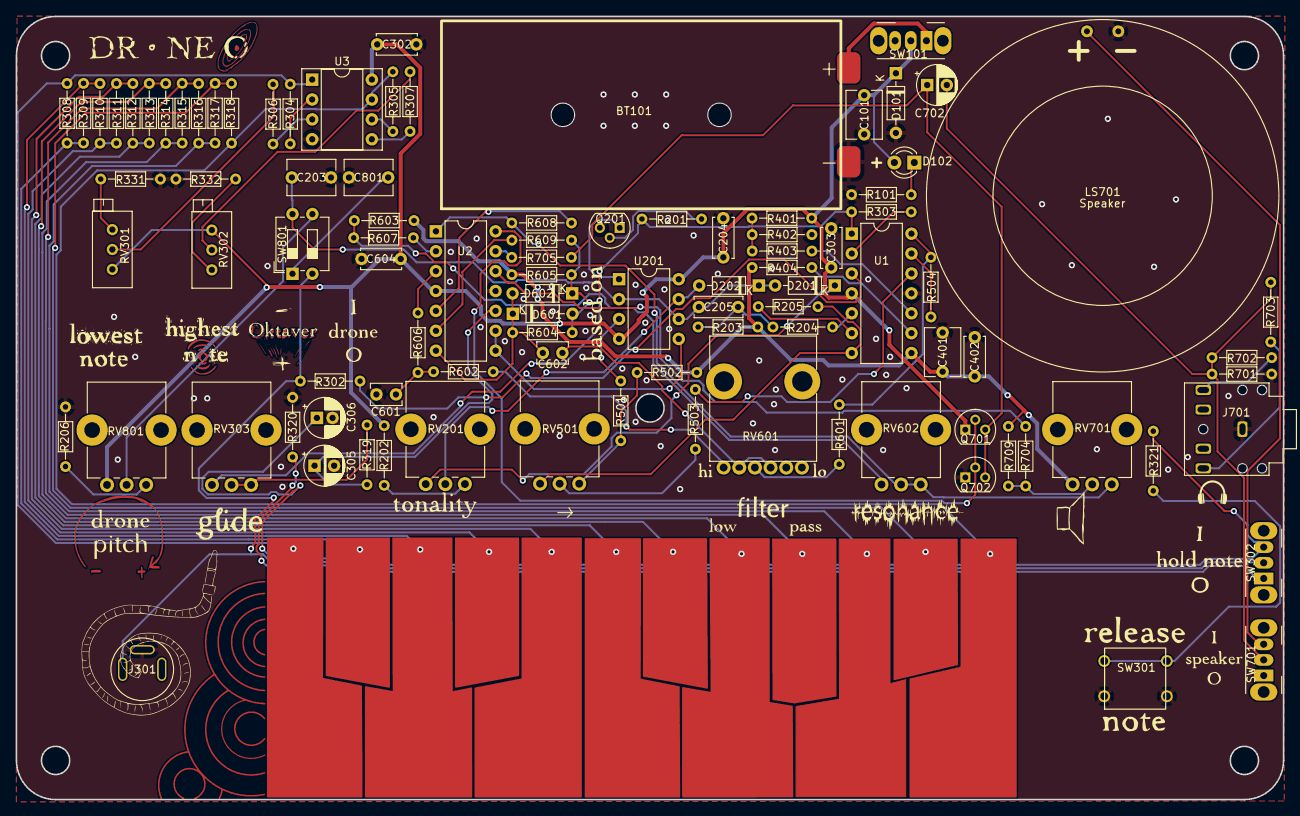
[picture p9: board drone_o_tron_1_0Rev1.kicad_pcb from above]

Board: 2 copper layers, 161.8 x 100.0 mm, 99 parts (0 on the bottom side), 78 nets.

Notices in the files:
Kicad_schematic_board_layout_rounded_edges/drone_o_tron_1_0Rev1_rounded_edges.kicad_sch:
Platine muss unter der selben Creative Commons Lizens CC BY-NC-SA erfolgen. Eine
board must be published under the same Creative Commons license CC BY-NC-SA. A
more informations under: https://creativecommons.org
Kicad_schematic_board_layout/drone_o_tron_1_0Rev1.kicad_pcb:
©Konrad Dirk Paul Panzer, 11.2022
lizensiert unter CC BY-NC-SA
